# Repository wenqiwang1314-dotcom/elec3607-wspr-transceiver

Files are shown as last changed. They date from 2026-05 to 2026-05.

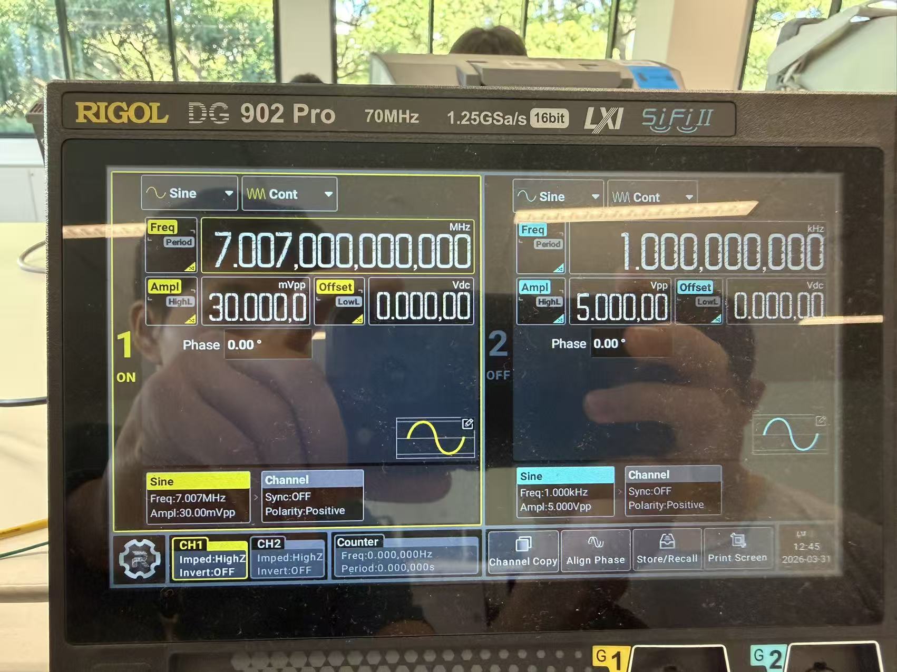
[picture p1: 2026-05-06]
report_images/partA_30mVpp_reference_input.jpg

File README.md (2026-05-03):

# ELEC3607 Assignment 1: WSPR Transceiver 任务设计

版本依据：Assignment 1 - WSPR Transceiver Version 0.4, 15 Apr 2026  
工程目录：`pcb_2026`  
原始 KiCad 工程：`bbb.kicad_pro`, `bbb.kicad_sch`, `bbb.kicad_pcb`  
最终提交：单个 `.zip`，包含 KiCad schematic、PCB design files、IEEE conference format 报告。

## 1. 项目目标

本项目在实验课 WSPR-SDR 接收机基础上完成两个修改：

1. Part A：用 Si5351 剩余的 `CLK2` 输出实现 WSPR 发射软件，并通过硬连线 RF loopback 让已有接收机或教师 decoder board 解码。
2. Part B：从现有 PCB 出发，重新设计成收发一体 transceiver PCB。发射机输出需达到 `0.1 W into 50 ohms`，收发共用接收机 bandpass filter，收发切换由 GPIO 控制，新增器件来自 Element14 Australia。

评分重点不是解释旧 WSPR-SDR，而是清楚说明新增发射功能、RF loopback、功率放大、收发切换和 PCB 修改如何工作。

## 2. 本地 Resources 使用清单

| 资料 | 用途 |
|---|---|
| `Resources/wspr_coding_process.pdf` | Part A WSPR message 编码、symbol 生成、tone mapping 的主要依据。 |
| `Resources/Si5351-B.pdf` | Si5351 `CLK2` 输出频率、驱动强度、寄存器/I2C 控制和硬件限制。 |
| `Resources/QS11-2010-Taylor.pdf` | WSPR 协议背景、4-FSK、tone spacing、解码约束和报告引用。 |
| `Resources/Tayloe_mixer_x3a.pdf` | 原接收机 quadrature sampling/Tayloe mixer 信号路径说明。 |
| `Resources/A Comparison of Affordable, Self-Assembled Software-Defined Radio Receivers Using Quadrature Sampling Down-Conversion.pdf` | 报告风格和 SDR 接收架构描述参考。 |
| `Resources/ABCs of Probes 60W-6053-15.pdf` | 示波器探头、RF/低电平测量误差说明。 |
| `Resources/emc_and_signal_integrity_ce_magazine_march-april_1999.pdf` | PCB layout、RF grounding、return path 和串扰风险说明。 |
| `Resources/website.txt` | WSPR/SDR 相关网页入口。 |

## 3. 团队分工建议

| 角色 | 主要负责 | 输出物 |
|---|---|---|
| Software lead | `wspr_transmit` C 程序、WSPR 编码、Si5351 `CLK2` 控制、CLI 参数验证 | C 源码、运行说明、软件测试记录 |
| Hardware modification lead | Part A 现有 PCB 飞线/RF loopback/衰减网络/照片/测量 | 修改原理图、PCB 照片、测试数据 |
| RF/PCB lead | Part B PA、T/R switch、共享 BPF、KiCad schematic/PCB layout | 更新后的 `.kicad_sch`, `.kicad_pcb`, BOM |
| Report/integration lead | IEEE 报告、图表、参考文献、提交 zip 检查 | 4 页以内 PDF 报告、最终 zip |

每个人都需要能在 oral discussion 中解释自己部分之外的完整信号路径。

## 4. Part A 任务：WSPR 发射与 RF Loopback

### A1. 明确 WSPR 发射需求

- 输入格式：`./wspr_transmit CALLSIGN LOCATOR POWER`
- 示例：`./wspr_transmit VK2AAX QF56 3`
- CLI 参数检查：
  - callsign：合法 WSPR callsign 格式，报告中说明支持范围。
  - locator：4 字符 Maidenhead grid，例如 `QF56`。
  - power：WSPR dBm power code，示例 `3` 代表作业要求输入格式，实际含义需在报告中解释。
- 输出信号：
  - WSPR uses 4-FSK.
  - 每个 symbol 选择 4 个 tone 之一。
  - tone spacing 约 `1.4648 Hz`。
  - 一帧 WSPR 标准消息共 `162` symbols，持续约 `110.6 s`。
- 软件必须使用 Si5351 `CLK2` 产生 RF tone，不使用空中发射。

完成标准：

- 程序能接受示例命令并生成确定的 WSPR symbol/tone 序列。
- 参数错误时给出 usage。
- 报告中给出 symbol generation 流程图或伪代码。

### A2. 编写 `wspr_transmit` C 程序

建议文件：

- `software/wspr_transmit.c`
- `software/wspr_encode.c`
- `software/wspr_encode.h`
- `software/si5351_control.c`
- `software/si5351_control.h`
- `software/Makefile`

软件模块任务：

1. `main()` 解析 `CALLSIGN LOCATOR POWER`。
2. WSPR message packing：将 callsign、locator、power 打包成 WSPR message bits。
3. FEC/interleaving/sync：按 `Resources/wspr_coding_process.pdf` 生成 162 个 symbols。
4. Tone scheduler：将 symbol 映射到 `f0 + symbol * 1.4648 Hz`。
5. Si5351 driver：通过 I2C 更新 `CLK2` 输出频率。
6. Timing：每个 symbol 周期约 `110.592 / 162 = 0.6827 s`，尽量减少切换抖动。
7. Logging：启动时打印 callsign、locator、power、base frequency、frame start time。

建议测试：

- Unit test：固定输入 `VK2AAX QF56 3` 时 symbol 序列可重复。
- Dry run：不控制 Si5351，只打印 tone frequency 和 symbol index。
- Hardware run：连接示波器/频率计确认 `CLK2` 有 4 个细小频偏。

完成标准：

- `make` 后生成 `wspr_transmit`。
- `./wspr_transmit VK2AAX QF56 3` 能运行完整帧。
- 报告附核心 C 代码片段，不必粘贴全部文件。

### A3. 音频 loopback 小步验证

用途：在 RF loopback 之前先验证编码和解码链路。

任务：

- 生成等效 audio baseband 4-FSK tone 序列。
- 将 audio 输出接入现有接收/解码链路。
- 用实验室 receiver/decoder 确认 callsign、locator、power 可解出。

完成标准：

- 记录一次成功 decode 的截图或串口/终端输出。
- 在报告中说明 audio loopback 只是中间验证，不是最终 RF 方案。

### A4. RF loopback 硬件修改

目标：将 Si5351 `CLK2` RF 输出硬连线接回 receiver RF input，不经过天线空中传播。

建议电路：

```text
Si5351 CLK2
    |
    |-- DC blocking capacitor
    |
  resistive attenuator / level-setting network
    |
    |-- optional test point
    |
receiver RF input before existing bandpass/mixer chain
```

关键设计点：

- 不应直接把过大的 `CLK2` 方波灌入 receiver input。
- 通过电容隔直和电阻衰减控制接收机输入电平。
- 尽量保持短接线、公共地可靠、避免 RF pickup。
- 报告需要包含：
  - 修改电路图。
  - 修改后 PCB 照片。
  - 衰减网络计算。
  - 实测 `CLK2` 输出幅度、receiver input 幅度、decode 结果。

完成标准：

- 教师 decoder board 或本组 WSPR receiver 能从 RF loopback 解码。
- 测量记录包含仪器型号/探头设置/测量点。

### A5. Part A 测量清单

| 测量项 | 测量点 | 期望记录 |
|---|---|---|
| `CLK2` RF 输出 | Si5351 `CLK2` 或飞线起点 | 频率、幅度、波形 |
| 衰减后 RF | receiver input | 幅度，确认不会过载 |
| Tone spacing | `CLK2` 或 receiver output | 约 `1.4648 Hz` 间隔，或解释仪器分辨率限制 |
| Decode 结果 | WSPR receiver/decoder | callsign、locator、power、SNR/time offset/frequency offset |
| 电源电流 | 板级输入 | RX/TX 状态对比 |

## 5. Part B 任务：Transceiver PCB 设计

### B1. 建立 KiCad 修改分支

任务：

- 复制原始工程，避免破坏 baseline。
- 建议新文件命名：
  - `wspr_transceiver.kicad_pro`
  - `wspr_transceiver.kicad_sch`
  - `wspr_transceiver.kicad_pcb`
- 保持 PCB 外形尺寸与原始 `bbb.kicad_pcb` 一致。
- 保留原接收机必要链路，只修改收发相关电路。

完成标准：

- KiCad ERC/DRC 主要错误已处理或在报告中解释。
- 原始板框尺寸未改变。

### B2. Part B RF 信号路径定义

建议完整信号路径：

```text
TX mode:
Si5351 CLK2
 -> output shaping / attenuator
 -> driver / PA
 -> low-pass or harmonic filtering if required
 -> GPIO-controlled T/R switch
 -> shared bandpass filter
 -> 50 ohm RF output / loopback/test connector

RX mode:
50 ohm RF input
 -> GPIO-controlled T/R switch
 -> shared bandpass filter
 -> existing receiver mixer / audio chain
```

报告必须说明：

- GPIO 为 RX 时，PA 输出不能反灌 receiver。
- GPIO 为 TX 时，receiver input 被隔离或保护。
- Bandpass filter 被 TX 和 RX 共用，符合题目要求。
- 50 ohm 系统如何匹配。

### B3. 0.1 W into 50 ohms 设计计算

设计目标：

- 输出功率：`Pout = 0.1 W = 20 dBm`
- 负载：`R = 50 ohms`
- 正弦波等效：
  - `Vrms = sqrt(P * R) = sqrt(0.1 * 50) = 2.236 V`
  - `Vpk = 3.162 V`
  - `Vpp = 6.324 V`
  - `Irms = Vrms / R = 44.7 mA`

任务：

- 选择 PA 架构：小信号 driver + RF transistor/MOSFET，或可买到的 RF gain block/PA 器件。
- 计算所需 gain：由 Si5351 `CLK2` 可用输出电平推算到 `20 dBm`。
- 设计输出匹配网络和 bias。
- 检查功耗和热耗散。
- 检查 harmonic suppression，必要时加入 LPF 或利用共享 BPF 后的选择性。

完成标准：

- 报告给出 PA 电路图、关键元件值、偏置点、预期 gain、预期输出功率。
- BOM 中新增器件来自 Element14 Australia，并记录订购编号、封装、库存检查日期。

### B4. GPIO 控制收发切换

可选方案：

1. RF switch IC：GPIO 直接/经电平转换控制，优点是隔离度和插损明确。
2. 二极管/模拟开关方案：成本低，但需要认真计算 RF 隔离、插损和偏置。
3. 小继电器：隔离好，但体积、电流、切换速度和 PCB 尺寸可能不利。

任务：

- 确定 GPIO 电压标准和可用 pin。
- 设计默认安全状态：上电默认 RX 或 TX disabled。
- 增加 PA enable，避免 RX 时 PA 自激或泄漏。
- 在原理图中清楚标注 `TX_EN` 或 `TR_CTRL`。

完成标准：

- 原理图中可从 GPIO 追踪到 RF switch/PA enable。
- 报告给出 TX/RX 两种状态的开关真值表。

示例真值表：

| GPIO `TR_CTRL` | 模式 | PA | RF path |
|---|---|---|---|
| `0` | RX | Off | RF input -> BPF -> receiver |
| `1` | TX | On | PA -> BPF -> RF output |

### B5. PCB layout 修改任务

任务：

- 保持原 PCB 大小和安装孔。
- PA 到 RF connector 的路径短、宽度接近 50 ohm 微带线要求。
- PA 输出和 receiver input 保持物理隔离。
- RF switch 靠近 BPF 或 RF connector，减少 stub。
- PA 电源就近放置 decoupling capacitors。
- 高电流/高频回流路径下方保持连续地。
- 增加测试点：
  - `TP_CLK2`
  - `TP_PA_IN`
  - `TP_PA_OUT`
  - `TP_TR_CTRL`
  - `TP_RX_IN`

完成标准：

- KiCad DRC 通过，或每个剩余 issue 都有理由。
- 关键 RF 网络可在 PCB 上清楚追踪。
- 生成 Gerber/Drill/BOM/position files 供提交或制造参考。

### B6. Element14 器件选择任务

需要记录每个新增器件：

- Manufacturer part number
- Element14 order code
- Package/footprint
- Datasheet URL
- 关键参数：频率范围、gain、P1dB/output power、supply voltage、insertion loss/isolation/current rating
- 查询日期

候选类别：

- RF amplifier / transistor / MOSFET
- RF switch 或 PIN diode
- Matching inductors/capacitors
- Attenuator resistors
- RF connector / test point
- Power decoupling capacitors

注意：库存和价格会变化，最终报告中要写明查询日期。

## 6. 报告结构建议（IEEE Conference Format，最多 4 页）

建议页数分配：

| 部分 | 建议长度 | 内容 |
|---|---:|---|
| Title/Abstract | 0.25 页 | 一句话说明实现了 RF loopback transmitter 和 transceiver PCB redesign。 |
| I. Introduction | 0.25 页 | 项目目标、频段、WSPR-SDR 到 transceiver 的变化。 |
| II. Part A Transmitter Implementation | 1.25 页 | WSPR 编码、`CLK2` 发射、CLI、RF loopback、衰减计算、软件/硬件框图。 |
| III. Part A Measurements | 0.5 页 | 波形、频率、电平、decode 结果、照片。 |
| IV. Part B Transceiver Hardware | 1.25 页 | PA、0.1 W 计算、T/R switch、共享 BPF、GPIO 真值表、完整信号路径。 |
| V. PCB Layout and Expected Performance | 0.5 页 | PCB 截图、RF layout 决策、预期功率/隔离/风险。 |
| References | 0.25 页 | WSPR、Si5351、器件 datasheet、Resources 中论文。 |

报告中必须放在正文的证据：

- Part A 修改电路图。
- Part A 修改后 PCB 照片。
- `wspr_transmit` 核心 C 代码。
- Part A 测量数据和 decode 结果。
- Part B 完整 schematic。
- Part B PA 和 50 ohm 功率计算。
- Part B PCB layout 截图。
- 新增器件 BOM。

## 7. 最终提交检查表

- [ ] `wspr_transmit` C 源码和 Makefile 已包含在 zip 中。
- [ ] `./wspr_transmit VK2AAX QF56 3` 已测试。
- [ ] RF loopback 修改电路图已画出。
- [ ] 修改后 PCB 照片已放入报告。
- [ ] 至少一次 WSPR decode 成功结果已记录。
- [ ] Part B KiCad schematic 已更新。
- [ ] Part B PCB layout 已更新且板框尺寸不变。
- [ ] PA 设计目标达到 `0.1 W into 50 ohms`，计算写入报告。
- [ ] T/R switch 由 GPIO 控制，真值表写入报告。
- [ ] 新增器件均来自 Element14 Australia，BOM 包含 order code。
- [ ] ERC/DRC 已运行，剩余问题已解释。
- [ ] IEEE conference format 报告不超过 4 页。
- [ ] zip 中包含 report PDF、KiCad files、source code、必要图片/测量数据。

## 8. 风险与应对

| 风险 | 影响 | 应对 |
|---|---|---|
| WSPR 编码实现错误 | decoder 无法解码 | 先做 dry-run 和 audio loopback，再做 RF loopback。 |
| Si5351 频率更新时间抖动 | tone 不稳定，SNR 下降 | 预先计算 tone frequencies，symbol 边界只做必要 I2C 更新。 |
| RF loopback 电平过高 | receiver overload 或损坏 | 加电容隔直和可计算衰减网络，先从大衰减开始测试。 |
| PA harmonic 太高 | 输出不干净，decoder 测试失败 | 使用共享 BPF，必要时在 PA 后加 LPF。 |
| T/R switch 隔离不足 | TX 泄漏进 RX 或 RX 灵敏度下降 | 选择隔离度足够的 RF switch，layout 缩短 stub。 |
| PCB 尺寸限制 | 新增 PA/switch 放不下 | 优先使用小封装器件，并移除不必要测试结构。 |
| Element14 缺货 | BOM 不可采购 | 尽早锁定 2 个可替代器件并记录查询日期。 |

## 9. 建议时间线

| 时间 | 软件 | 硬件/PCB | 报告 |
|---|---|---|---|
| Day 1 | 完成 WSPR 编码资料阅读和代码框架 | 找到 `CLK2`、receiver input、可用 GPIO | 建立报告模板 |
| Day 2 | 完成 symbol 生成和 dry-run | 设计 Part A 衰减/loopback 电路 | 画 Part A 框图 |
| Day 3 | 接入 Si5351 `CLK2` 控制 | 焊接 Part A 修改并拍照 | 写 Part A 方法 |
| Day 4 | audio/RF loopback debug | 完成 Part B PA 和 T/R switch 原理图 | 加入测量表 |
| Day 5 | 整理代码和运行说明 | 完成 PCB layout 和 ERC/DRC | 写 Part B 设计 |
| Day 6 | 最终复测 | 生成 Gerber/BOM/截图 | 压缩到 4 页并交叉检查 |

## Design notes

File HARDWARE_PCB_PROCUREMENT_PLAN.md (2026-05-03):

# WSPR Transceiver 硬件 / PCB / 采购优先规划

起始日期：2026-04-28  
目标：优先解决采购周期长、PCB 返工慢、硬件风险高的问题。软件可以并行推进，但不能阻塞器件采购和 PCB 方案冻结。

## 1. 核心结论

硬件任务的关键路径是：

```text
确定 TX/RX RF 架构
 -> 选 PA 与 T/R switch
 -> Element14 下单主器件和备选器件
 -> 原理图冻结
 -> footprint/封装核对
 -> PCB layout 冻结
 -> ERC/DRC + Gerber/BOM 输出
 -> 板级 bring-up 测试
```

必须先采购的不是所有小阻容，而是这些长周期/易缺货/封装影响 PCB 的器件：

1. PA final transistor 或 RF gain block。
2. T/R switch：RF switch IC 或 PIN diode switch 所需二极管。
3. RF matching/filter 电感电容，尤其是 RF-grade C0G/NP0 和高 Q 电感。
4. SMA/RF connector、test point、attenuator/matching 电阻。
5. PA 电源去耦、电源开关/enable 相关器件。

## 2. 当前原板可复用信息

从现有工程可见的关键网络：

| 原板网名 | 用途 | 新设计动作 |
|---|---|---|
| `CLK2` | Si5351 剩余输出，用作 TX RF source | 接入 TX driver / PA input。 |
| `BPFIN` | bandpass filter input | 改成 T/R switch 后的共享 BPF 输入。 |
| `BPFOUT` | bandpass filter output | RX 时接 mixer，TX 时视滤波器方向和拓扑决定是否反向使用。 |
| `RFIN` | receiver RF input path | RX path 保留，TX 时隔离/保护。 |
| `RFOUT` | RF amplifier/mixer 相关输出网 | 核对原接收机链路，不要误接为 TX power output。 |
| `U2 Si5351A-B-GT` | 频率源 | `CLK2` 需要新增 TX path footprint 和 test point。 |
| `U6 SMA` | 原 RF 接口 | 尽量复用为收发共用 50 ohm RF port。 |

硬件规划应先在 KiCad 中把这些网名重命名/标注清楚，例如新增：

- `TX_RF_RAW`
- `TX_PA_IN`
- `TX_PA_OUT`
- `TR_CTRL`
- `PA_EN`
- `ANT_50R`
- `BPF_SHARED_IN`
- `BPF_SHARED_OUT`

## 3. 架构冻结：两套方案并行保底

### 方案 A：分立 PA + PIN diode T/R switch（推荐优先推进）

理由：

- 低频 HF/WSPR 更容易用分立器件实现 0.1 W。
- PIN diode 可覆盖作业可能的 HF 频率，器件便宜，封装好焊。
- 即使 switch 性能一般，也容易调试和解释。

信号路径：

```text
TX:
Si5351 CLK2
 -> attenuator / square-wave shaping
 -> driver transistor
 -> class-C / class-E-ish PA final
 -> low-pass / harmonic cleanup if needed
 -> PIN diode T/R switch
 -> shared BPF
 -> SMA 50 ohm

RX:
SMA 50 ohm
 -> PIN diode T/R switch
 -> shared BPF
 -> existing RX amplifier/mixer path
```

必须设计：

- PA 输出目标：`0.1 W = 20 dBm into 50 ohms`。
- `Vrms = sqrt(0.1 * 50) = 2.236 V`
- `Vpp = 2 * sqrt(2) * 2.236 = 6.32 Vpp`
- `Irms = 2.236 / 50 = 44.7 mA`
- PA 要留 3 dB 余量，设计目标建议为 `23 dBm`，实际通过衰减或偏置调到 20 dBm。

采购优先件：

- 2N7000 / BS170 类 MOSFET 先买一批用于原型验证。
- RF BJT 小信号 driver 先买 5-10 个。
- PIN diode 至少买两种：低电阻优先、封装易焊优先。
- RF 电感电容按计算值上下各买一档。

### 方案 B：RF gain block + switch IC（作为备选）

理由：

- 原理图更整洁，50 ohm 接口明确。
- 缺点是价格高、频率下限/输出功率可能不完全满足。

注意：

- 搜到的 HMC741ST89ETR 是 50 MHz 到 3 GHz、输出约 +18.5 dBm 级别，单颗离 20 dBm 目标略低，而且若项目频率在 HF，需要确认 50 MHz 下限是否不可接受。
- 很多现成 RF switch IC 下限从 100 MHz、1 GHz 或更高开始，不适合 HF WSPR，不能只看“SPDT RF switch”就下单。
- 如果选 switch IC，必须确认 minimum frequency、power handling、insertion loss、isolation、control voltage 和 footprint。

## 4. Element14 初筛器件方向

下表是采购前筛选方向，不是最终 BOM。下单前必须重新打开 Element14 页面确认库存、交期、价格和是否停产。

| 类别 | 候选方向 | 初筛观察 | 风险 |
|---|---|---|---|
| PA final | 2N7000 / BS170 类小 MOSFET | Element14 上 2N7000 有大量库存记录，便宜且易原型 | 不是专用 RF PA，HF 输出功率和效率要实测。 |
| RF driver | BFR92/BFR106 类 RF BJT | Element14 有 RF transistor 分类，SOT-23 易布局 | 需要偏置设计，不能直接当 100 mW final。 |
| PIN diode | BAR50 / BAP65 / HSMP 类 | PIN diode 适合 RF switch/attenuator，部分型号覆盖 10 MHz 以上 | 某些型号可能 no longer manufactured，要买替代件。 |
| RF switch IC | BGSA11 / F2912 / ADRF 系列 | 部分器件为 50 ohm switch，控制简单 | 频率下限、价格、封装和焊接难度可能不适合本作业。 |
| RF gain block | HMC741ST89E 类 | 50 ohm gain block、SOT-89、资料完整 | 频率下限 50 MHz，输出功率略低于 20 dBm 目标。 |
| L/C matching | C0G/NP0 RF capacitors，高 Q inductors | 影响 PA matching 和滤波器性能 | 普通 X7R 不适合频率/稳定性关键位置。 |

参考链接：

- Element14 2N7000: https://au.element14.com/on-semiconductor/2n7000/mosfet-n-channel-200ma-60v-to/dp/9845178
- Element14 BAR50-02V: https://au.element14.com/infineon/bar50-02v/diode-rf-pin-sc-79/dp/1095645
- Element14 HMC741ST89ETR: https://au.element14.com/analog-devices/hmc741st89etr/rf-amplifier-50mhz-to-3ghz-sot/dp/4419988
- Element14 RF / PIN diode category: https://au.element14.com/c/semiconductors-discretes/diodes-rectifiers/rf-pin-diodes

## 5. 采购策略：今天就能下的单

### 第一单：风险样品单（今天或最晚明天）

目的：不等最终 PCB，先买会影响架构的器件。

建议数量：

| 器件类别 | 数量 | 原因 |
|---|---:|---|
| PA final MOSFET/BJT 候选 | 每种 5-10 | 焊坏、调偏置、做 dead-bug 原型都需要余量。 |
| RF driver transistor | 5-10 | 驱动级可换型。 |
| PIN diode 候选 | 每种 10-20 | switch 可能要用 2-4 颗，且要做多种拓扑。 |
| RF C0G 电容 | 每值 10-20 | matching/filter 调试要换值。 |
| RF 电感 | 每值 5-10 | PA 输出网络和 LPF 调试。 |
| 50 ohm/attenuator 电阻 | 每值 20 | Pi/T attenuator 与终端匹配。 |
| SMA/test point | 2-5 | PCB 与飞线测试都需要。 |

第一单原则：

- 买主方案和备选方案，不要只买一个“看起来最对”的器件。
- 对 switch IC 这类贵/难焊器件，除非频率下限和封装已经确认，否则先不要压预算。
- 所有新增封装优先选 KiCad 标准库已有 footprint：SOT-23、SOT-223、SOT-89、0805、0603、SMA edge/through-hole。

### 第二单：PCB BOM 冻结单

触发条件：

- PA topology 已在面包板/dead-bug 或小板上能接近 20 dBm。
- T/R switch 在 RX/TX 两态下能连通/隔离。
- KiCad footprint 与 datasheet land pattern 已核对。

第二单内容：

- 最终型号主件。
- 最终 matching/filter 值。
- 备用器件 20%-50%。
- PCB assembly 需要的 reel/cut-tape 封装选项。

## 6. 日期规划（从 2026-04-28 开始）

| 日期 | 硬件/采购目标 | 输出物 | 是否阻塞 PCB |
|---|---|---|---|
| Apr 28 | 冻结 TX/RX 总体架构，列出 PA 与 switch 两套候选 | `hardware_decision_log.md` 初版，采购 basket 初版 | 是 |
| Apr 29 | 完成 Element14 第一单，下单主件+备选+RF L/C | 订单截图/BOM 记录，datasheet 链接 | 是 |
| Apr 30 | 画 Part B 原理图草案：PA、T/R switch、shared BPF 接法 | KiCad schematic draft | 是 |
| May 1 | footprint 核对，确定板上可放位置，检查原板尺寸 | footprint checklist，placement sketch | 是 |
| May 2 | PCB layout 第 1 版：只追关键 RF path 和电源路径 | `wspr_transceiver.kicad_pcb` v1 | 否 |
| May 3 | ERC/DRC 第 1 轮，生成 BOM 草案 | DRC log，BOM v1 | 否 |
| May 4 | 器件到货后做 PA/switch 台架验证；若未到货，用仿真/计算补齐 | PA/switch measurement plan | 否 |
| May 5 | 根据实测或 datasheet 修正匹配、偏置、滤波器 | schematic v2，BOM v2 | 是 |
| May 6 | PCB layout 冻结，导出 Gerber/Drill/position | fabrication package | 是 |
| May 7+ | Bring-up/报告证据收集 | 波形、功率、切换真值表、照片 | 否 |

如果最终提交日期早于这个节奏，需要把 May 4 以后的“实测”改成“prototype test + expected performance”，但采购和 PCB 冻结仍然要在前两天完成。

## 7. 每日硬件检查表

### Day 0 / Apr 28

- [ ] 在 KiCad 中确认 `CLK2` 到新增 TX path 的可布线路径。
- [ ] 确认 SMA 到 BPF 的原始路径，决定 BPF 是否可双向共享。
- [ ] 决定 `TR_CTRL` GPIO 使用哪个 BeagleBone/board header pin。
- [ ] 建立候选 BOM 表，至少每个关键类别 2 个候选。
- [ ] 采购负责人把 Element14 basket 分享给全组复核。

### Day 1 / Apr 29

- [ ] 下第一单。
- [ ] 下载每个新增器件 datasheet，放到 `Resources/datasheets/`。
- [ ] 在 BOM 表记录 order code、数量、价格、库存、预计到货日期、查询日期。
- [ ] KiCad 新增 symbol/footprint 前先确认封装尺寸。

### Day 2 / Apr 30

- [ ] 画 PA 偏置、电源去耦、input attenuator。
- [ ] 画 T/R switch，包含 TX/RX 真值表。
- [ ] 明确 RX 保护：TX 时 receiver input 不可直接承受 PA 输出。
- [ ] 明确 TX harmonic cleanup：BPF 是否足够，不足则加 LPF。

### Day 3 / May 1

- [ ] 把关键器件放入 PCB：PA 靠近 BPF/switch，Si5351 `CLK2` 到 PA input 短。
- [ ] PA 电源走线加粗，就近放 `100 nF + 1 uF/10 uF`。
- [ ] 新增 test points：`TP_CLK2_TX`, `TP_PA_IN`, `TP_PA_OUT`, `TP_TR_CTRL`, `TP_ANT_50R`。
- [ ] 检查地回流：PA、switch、BPF 下方尽量连续地。

### Day 4 / May 2

- [ ] 完成 RF path layout。
- [ ] 检查 board outline 与原 `bbb.kicad_pcb` 一致。
- [ ] 关键 RF 线尽量短、少过孔、少 stub。
- [ ] 输出 Gerber 预览截图给报告使用。

## 8. PCB 设计冻结标准

### 原理图冻结必须满足

- [ ] `CLK2 -> PA -> T/R switch -> shared BPF -> SMA` TX path 可追踪。
- [ ] `SMA -> T/R switch -> shared BPF -> RX` RX path 可追踪。
- [ ] `TR_CTRL` GPIO 控制 switch。
- [ ] `PA_EN` 或同等机制保证 RX 时 PA 关闭。
- [ ] 所有 RF port 有 DC blocking 或明确 DC bias 处理。
- [ ] PA 输出功率计算写在原理图 note 或报告草稿中。

### PCB 冻结必须满足

- [ ] 板框尺寸不变。
- [ ] 新增器件 footprint 与 datasheet land pattern 对照完成。
- [ ] PA 输出到 BPF/switch/SMA 的路径最短。
- [ ] RX input 和 PA output 不平行长距离靠近。
- [ ] 每个新增 IC/PA 管有近端 decoupling。
- [ ] DRC 通过，或剩余 DRC issue 有说明。
- [ ] 生成 Gerber/Drill/BOM/position files。

## 9. Bring-up 测试顺序

不能第一次上电就直接发 0.1 W。顺序如下：

1. 不焊 PA final，检查 3.3 V/5 V 电源和 `TR_CTRL`。
2. 焊 switch，低功率信号源测 RX path 插损和 TX path 连通。
3. 焊 PA driver，不焊 final 或限流供电，测 `CLK2` 到 `PA_IN`。
4. 焊 PA final，先接 20 dB attenuator + 50 ohm dummy load。
5. 从低 duty / 短时间 TX 开始，测电流和输出波形。
6. 达到接近 20 dBm 后再接共享 BPF，检查谐波/输出电平。
7. 切 RX 模式，确认 PA 关闭且 receiver 没有被强信号损坏。

报告证据：

- TX output into 50 ohm 的电压或功率计算。
- `TR_CTRL=0/1` 的状态表。
- PA 输出和 BPF 后输出波形。
- PCB layout 截图。
- 新增 BOM 表和 Element14 order code。

## 10. 风险优先级

| 优先级 | 风险 | 立即动作 |
|---|---|---|
| P0 | 买不到合适 T/R switch | 同时采购 PIN diode 和至少一个 switch IC 备选；方案 A 不依赖高价 IC。 |
| P0 | PA 达不到 20 dBm | PA 设计留 3 dB 余量；买 driver/final 多种候选；预留可调 matching。 |
| P1 | BPF 双向共享后插损/匹配变差 | PCB 上预留 0 ohm / DNP 位置，可改接 BPF 方向或旁路测试。 |
| P1 | TX 泄漏损坏 RX | RX path 加隔离和保护，bring-up 使用 attenuator/dummy load。 |
| P1 | 封装太难焊 | 优先选 SOT-23/SOT-89/0805，LGA/QFN 只作备选。 |
| P2 | PCB 空间不够 | 先放 PA/switch/BPF/SMA，其他测试点可删减。 |

## 11. 给团队的执行规则

- 硬件负责人每天更新一次 BOM 和 decision log。
- 采购下单不等软件完成。
- 每个关键器件至少有一个备选。
- 下单前必须由另一名组员复核 datasheet 的 frequency、power、voltage、footprint。
- 任何“看起来可以”的 RF switch，必须先查 minimum operating frequency。
- 报告里只写最终采用方案，但保留 decision log 供 oral discussion 解释为什么没选其他方案。

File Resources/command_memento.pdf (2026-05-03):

## GNU/Linux most wanted

## Summary of most useful commands

©Copyright 2025-2005, Bootlin.
Free to share under the terms of the Creative Commons Attribution-ShareAlike 3.0 license (http://creativecommons.org)

Electronic version, sources, translations and updates: http://bootlin.com/doc/legacy/command-line/ (http://free-electrons.com/doc/legacy/command-line/)

Thanks to Michel Blanc, Hermann J. Beckers and Thierry Grellier.

Latest update: Oct 28, 2025

## Handling files and directories

Create a directory:

## mkdir dir

Create nested directories:

## mkdir -p dir1/dir2

Changing directories:

## cd newdir

cd .. (parent directory)
cd - (previous directory)
cd (home directory)
cd ~bill (home directory of user bill)

Print the working (current) directory: pwd
Copy a file to another:

## cp source_file dest_file

Copy files to a directory:

## cp file1 file2 dir

Copy directories recursively:

## cp -r source_dir dest_dir rsync -a source_dir/ dest_dir/

Create a symbolic link:

## ln -s linked_file link

Rename a file, link or directory:

## mv source_file dest_file

Remove files or links:

## rm file1 file2

Remove empty directories:

## rmdir dir

Remove non-empty directories:

## rm -rf dir Listing files

List all “regular” files (not starting with .) in the current directory:
ls

Display a long listing:

## ls -l

List all the files in the current directory, including “hidden” ones (starting with .):

## ls -a

List by time (most recent files first):

## ls -t

List by size (biggest files first)

## ls -S

List with a reverse sort order:

## ls -r

Long list with most recent files last:

## ls -ltr Displaying file contents

Concatenate and display file contents:

## cat file1 file2

Display the contents of several files (stopping at each page):

## more file1 file2

less file1 file2 (better: extra features)

Display the first 10 lines of a file:

## head -10 file

Display the last 10 lines of a file:

## tail -10 file File name pattern matching

Concatenate all “regular” files:

## cat *

Concatenate all “hidden” files:

## cat .*

Concatenate all files ending with .log:

## cat *.log

List “regular” files with bug in their name:

## ls *bug*

List all “regular” files ending with . and a single character:
ls *.?

## Handling file contents

Show only the lines in a file containing a given substring:

## grep substring file

Case insensitive search:

## grep -i substring file

Showing all the lines but the ones containing a substring:

## grep -v substring file

Search through all the files in a directory:

## grep -r substring dir

Sort lines in a given file:

## sort file

Sort lines, only display duplicate ones once:

## sort -u file (unique) Changing file access rights

Add write permissions to the current user:

## chmod u+w file

Add read permissions to users in the file group:

## chmod g+r file

Add execute permissions to other users:

## chmod o+x file

Add read + write permissions to all users:

## chmod a+rw file

Make executable files executable by all:

## chmod a+rX *

Make the whole directory and its contents accessible by all users:

## chmod -R a+rX dir (recursive)

## Comparing files and directories

Comparing 2 files:

## diff file1 file2

Comparing 2 files (graphical):

## gvimdiff file1 file2 tkdiff file1 file2 meld file1 file2

Comparing 2 directories:

## diff -r dir1 dir2 Looking for files

Find all files in the current (.) directory and its subdirectories with log in their name:

## find . -name “*log*”

Find all the .pdf files in dir and subdirectories and run a command on each:

## find . -name “*.pdf” -exec xpdf {} ';'

Quick system-wide file search by pattern (caution: index based, misses new files):

## locate “*pub*” Redirecting command output

Redirect command output to a file:

## ls *.png > image_files

Append command output to an existing file:

## ls *.jpg >> image_files

Redirect command output to the input of another command:

## cat *.log | grep error Job control

Show all running processes:

## ps -ef

Live hit-parade of processes (press P, M, T: sort by Processor, Memory or Time usage):

## top

Send a termination signal to a process:
kill <pid> (number found in ps output)

Have the kernel kill a process:

## kill -9 <pid>

Kill all processes (at least all user ones):

## kill -9 -1

Kill a graphical application:
xkill (click on the program window to kill)

## File and partition sizes

Show the total size on disk of files or directories (disk usage):

## du -sh dir1 dir2 file1 file2

Number of bytes, words and lines in file:
wc file (word count)

Show the size, total space and free space of the current partition:
df -h .

Display these info for all partitions:

## df -h Compressing

Compress a file:

## gzip file (.gz format)

bzip2 file (.bz2 format, better)
lzma file (.lzma format, best compression) xz file (.xz format, best for code)

Uncompress a file:

## gunzip file.gz bunzip2 file.bz2 unlzma file.lzma unxz file.xz Archiving

Create a compressed archive (tape archive):

## tar zcvf archive.tar.gz dir tar jcvf archive.tar.bz2 dir tar Jcvf archive.tar.xz dir tar --lzma -cvf archive.tar.lzma

Test (list) a compressed archive:

## tar tvf archive.tar.[gz|bz2|lzma|xz]

Extract the contents of a compressed archive:

## tar xvf archive.tar.[gz|bz2|lzma|xz]

tar options:
c: create
t: test
x: extract
j: on the fly bzip2 (un)compression J: on the fly xz (un)compression
z: on the fly gzip (un)compression

Handling zip archives

## zip -r archive.zip <files> (create) unzip -t archive.zip (test / list) unzip archive.zip (extract) Printing

Send PostScript or text files to queue:

## lpr -Pqueue f1.ps f2.txt (local printer)

List all the print jobs in queue:

## lpq -Pqueue

Cancel a print job number in queue:

## cancel 123 queue

Print a PDF file:

## pdf2ps doc.pdf lpr doc.ps

View a PostScript file:

## ps2pdf doc.ps xpdf doc.pdf User management

List users logged on the system:

## who

Show which user I am logged as:

## whoami

Show which groups user belongs to:

## groups user

Tell more information about user:

## finger user

Switch to user hulk:

## su - hulk

Switch to super user (root):
su - (switch user)
su (keep same directory and environment)

## Time management

Wait for 60 seconds:

## sleep 60

Show the current date:

## date

Count the time taken by a command:

## time find_charming_prince -cute -rich Command help

Basic help (works for most commands):

## grep --help

Access the full manual page of a command:

## man grep Misc commands

Basic command-line calculator

## bc -l Basic system administration

Change the owner and group of a directory and all its contents:

## sudo chown -R newuser.newgroup dir

Reboot the machine in 5 minutes:

## sudo shutdown -r +5

Shutdown the machine now:

## sudo shutdown -h now

Display all available network interfaces:

## ip -a

Assign an IP address to a network interface:

## sudo ip addr add 207.46.130.108/24 dev eth0

Bring up/down a network interface:

## sudo ip link set eth0 [up|down]

Define a default gateway for packets to machines outside the local network: sudo ip route add default via 192.168.0.1
Delete the default route:
sudo ip route del default via 192.168.0.1
Test networking with another machine:

## ping 207.46.130.108

Create or remove partitions on the first IDE hard disk:

## fdisk /dev/hda1

Create (format) an ext3 filesystem:

## mkfs.ext3 /dev/hda1

Create (format) a FAT32 filesystem:

## mkfs.vfat -v -F 32 /dev/hda2

Mount a formatted partition:

## mkdir /mnt/usbdisk (just do it once) sudo mount /dev/uba1 /mnt/usbdisk

Mount a filesystem image (loop device):

## sudo mount -o loop fs.img /mnt/fs

Unmount a filesystem:

## sudo umount /mnt/usbdisk

Check the system kernel version:

## uname -a

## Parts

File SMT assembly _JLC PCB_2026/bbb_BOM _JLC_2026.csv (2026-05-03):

Comment | Designator | Footprint
0.1uF | C1,C3,C4,C5,C6,C7,C8,C9,C10 | Capacitor_SMD:C_0805_2012Metric
0.01uF | C2 | Capacitor_SMD:C_0805_2012Metric
3300pF | C11,C12 | Capacitor_SMD:C_0805_2012Metric
100nF | C13 | Capacitor_SMD:C_0805_2012Metric
10uF | C14 | Capacitor_SMD:C_0805_2012Metric
33pF | C20,C25,C29 | Capacitor_SMD:C_0805_2012Metric
27pF | C21,C26,C30 | Capacitor_SMD:C_0805_2012Metric
270pF | C22 | Capacitor_SMD:C_0805_2012Metric
680pF | C23,C27,C31 | Capacitor_SMD:C_0805_2012Metric
22pF | C24,C28,C32 | Capacitor_SMD:C_0805_2012Metric
TestPoint_Small | CLK0_TP4,CLK1_TP5,Iout_TP6,Qout_TP7,RFIN_TP7,RFOUT_TP8,SCL_TP2,SDA_TP3,XA_TP1 | TestPoint:TestPoint_Keystone_5000-5004_Miniature
LED yellow | D1 | Diode_SMD:D_0603_1608Metric
LED blue | D2 | Diode_SMD:D_0603_1608Metric
GND BRIDGE | GND_TP0 | TestPoint:TestPoint_Bridge_Pitch7.62mm_Drill1.3mm
Conn_02x14_Odd_Even | J1 | Connector_PinHeader_2.54mm:PinHeader_2x14_P2.54mm_Vertical
Conn_02x20_Odd_Even | J2 | Connector_PinHeader_2.54mm:PinHeader_2x20_P2.54mm_Vertical
FC68131 | J3 | AudioJack:FC68131
Inductor L1 | J4 | TerminalBlock_Phoenix:TerminalBlock_Phoenix_MPT-0,5-2-2.54_1x02_P2.54mm_Horizontal
Inductor L2 | J5 | TerminalBlock_Phoenix:TerminalBlock_Phoenix_MPT-0,5-2-2.54_1x02_P2.54mm_Horizontal
Inductor L3 | J6 | TerminalBlock_Phoenix:TerminalBlock_Phoenix_MPT-0,5-2-2.54_1x02_P2.54mm_Horizontal
470 | R1,R3 | Resistor_SMD:R_0805_2012Metric
47 | R2 | Resistor_SMD:R_0805_2012Metric
220 | R4 | Resistor_SMD:R_0805_2012Metric
4.7k | R5,R6 | Resistor_SMD:R_0805_2012Metric
100 | R7 | Resistor_SMD:R_0805_2012Metric
10K | R8,R9 | Resistor_SMD:R_0805_2012Metric
62 | R10 | Resistor_SMD:R_0805_2012Metric
200 | R11 | Resistor_SMD:R_0805_2012Metric
50 | R20,R21 | Resistor_SMD:R_0805_2012Metric
THS4304 | U1 | Package_TO_SOT_SMD:SOT-23-5
Si5351A-B-GT | U2 | Package_SO:MSOP-10_3x3mm_P0.5mm
TS3A5017 | U3 | Package_SO:SOIC-16_3.9x9.9mm_P1.27mm
TL972 | U4 | Package_SO:SOIC-8-1EP_3.9x4.9mm_P1.27mm_EP2.29x3mm
LD1117S33TR_SOT223 | U5 | Package_TO_SOT_SMD:SOT-223-3_TabPin2
BWSMA-KE-P001 | U6 | BWSMA-KE-P001:BWSMA-KE-P001
Crystal | Y1 | Crystal:Crystal_SMD_TXC_7M-4Pin_3.2x2.5mm

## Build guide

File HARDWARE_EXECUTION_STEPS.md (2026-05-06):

# WSPR Transceiver 硬件负责人执行步骤

负责人范围：Part A 的 RF loopback 硬件改造 + Part B 的 transceiver PCB 新硬件设计。  
起始日期：2026-05-03。  
目标：尽快冻结硬件方案、采购关键器件、完成 KiCad 原理图和 PCB，并为报告准备可解释的设计证据。

## 0. 你要交付什么

你的硬件部分最终必须能回答这几个问题：

1. `CLK2` 发射信号如何进入 RF 发射链路？
2. 发射输出如何达到 `0.1 W into 50 ohms`？
3. 发射器和接收器如何共用原来的 bandpass filter？
4. GPIO 如何切换 TX/RX？
5. TX 时如何保护 RX 输入，RX 时如何关闭/隔离 PA？
6. PCB 尺寸如何保持与原板一致？
7. 新增器件为什么这样选，是否来自 Element14 Australia？

## 1. 第一天：先锁定原板 RF 路径

打开 KiCad 工程：

- `bbb.kicad_pro`
- `bbb.kicad_sch`
- `bbb.kicad_pcb`

在 schematic 和 PCB 中标记这些网络：

| 网名 | 你要确认的内容 |
|---|---|
| `CLK2` | Si5351 剩余输出，作为 TX RF source。 |
| `BPFIN` | 原 bandpass filter 输入。 |
| `BPFOUT` | 原 bandpass filter 输出。 |
| `RFIN` | 原 receiver RF input path。 |
| `RFOUT` | 原 RF amplifier/mixer 相关网络，注意不要误认为最终 TX output。 |
| `U6 SMA` | 原 RF 接口，优先复用为收发共用 50 ohm 端口。 |

执行动作：

1. 在原理图截图上用箭头画出原 RX 路径：

```text
SMA / RFIN -> BPFIN -> BPF -> BPFOUT -> receiver amplifier/mixer
```

2. 在 PCB 截图上圈出：
   - Si5351 `U2`
   - `CLK2`
   - BPF 电容/电感区域
   - SMA `U6`
   - receiver input/mixer 区域

3. 保存两张截图给报告使用：
   - `report_images/original_rf_path_schematic.png`
   - `report_images/original_rf_path_pcb.png`

完成标准：

- 你能指着图解释 RX 信号从 SMA 到 mixer 的路径。
- 你能说出 TX 新电路要插入在哪里。

## 1A. 根据 `BBBSchematic.jpg` 精确确定硬件架构

这张图不是只用来看元件名，而是用来决定 transceiver 的切入点。先按下面顺序把原板分成 6 个功能块。

### 1A.1 原接收机 RF 路径

从 `BBBSchematic.jpg` 可以读出原接收链：

```text
U6 SMA connector
 -> BPFIN
 -> Band Pass Filter
    R20, C20-C32, J4/J5/J6 external inductors, R21
 -> BPFOUT / RFIN
 -> C2 AC coupling
 -> U1 THS4304 RF amplifier
 -> RFOUT
 -> U3 TS3A5017 Tayloe / quadrature mixer
 -> MIXI+, MIXI-, MIXQ+, MIXQ-
 -> U4 TL972 audio amplifier
 -> J3 audio jack, Iout/Qout
```

这说明原板真正的 RF input/output 关系是：

| 位置 | 图中标号 | 硬件含义 |
|---|---|---|
| RF connector | `U6` | SMA 接口，当前只作为接收输入。 |
| BPF input | `BPFIN` | SMA 后进入 bandpass filter 的一端。 |
| BPF output | `BPFOUT` | bandpass filter 输出端。 |
| RX amplifier input | `RFIN` / `RFIN_TP7` | 与 `BPFOUT` 同一输入区域，经 `C2` 进入 U1。 |
| RX amplifier output | `RFOUT` / `RFOUT_TP8` | U1 输出，送入 mixer。 |
| Mixer input | `MIXIN` | U3 TS3A5017 的 RF mixer input。 |

结论：Part B 不应该把 PA 接到 `RFOUT`。`RFOUT` 是接收机 RF amplifier 的输出，不是天线输出。TX power path 应围绕 `CLK2`、`BPFOUT/BPFIN` 和 SMA 重新设计。

### 1A.2 原时钟和可用 TX 源

图中 `U2 Si5351A-B-GT` 有 3 个输出：

| Si5351 输出 | 原用途 | 新设计动作 |
|---|---|---|
| `CLK0` | 送 mixer 的 0 度 LO，标成 `MIXCLK0` | 保留，不改。 |
| `CLK1` | 送 mixer 的 90 度 LO，标成 `MIXCLK90` | 保留，不改。 |
| `CLK2` | 已引出但未用于 RX 主链 | 作为 WSPR TX RF source。 |

结论：TX 链从 `CLK2` 开始，不能占用 `CLK0/CLK1`，否则会破坏接收机 mixer。

### 1A.3 最推荐的 Part B 架构

为了最少改动原接收机，同时满足“发射机与接收机共用 bandpass filter”，推荐架构如下：

```text
RX mode:
SMA U6
 -> BPFIN
 -> shared BPF
 -> BPFOUT
 -> T/R switch RX throw
 -> RFIN / C2
 -> U1 THS4304
 -> RFOUT
 -> U3 mixer
 -> I/Q audio

TX mode:
Si5351 CLK2
 -> DC block / attenuator
 -> TX driver
 -> PA final
 -> PA output matching / optional LPF
 -> T/R switch TX throw
 -> BPFOUT
 -> shared BPF used in reverse direction
 -> BPFIN
 -> SMA U6
 -> 50 ohm load
```

这个方案的核心切入点是 `BPFOUT/RFIN`：

- `BPFOUT` 是 BPF 和 receiver amplifier 之间的天然分界点。
- 在 RX 模式，`BPFOUT` 接回 `RFIN/C2/U1`，原接收机照常工作。
- 在 TX 模式，`BPFOUT` 从 receiver input 断开，改接 PA output，让 TX 信号反向通过同一个 BPF 到 SMA。
- BPF 是 LC 被动网络，理论上双向可用；但原板的 50 ohm 电阻和实际插损必须测量/计算。

### 1A.4 为什么不从其他位置接入

不要选择这些错误切入点：

| 错误切入点 | 问题 |
|---|---|
| `RFOUT` | 这是 U1 接收放大器输出，会把 TX 功率打进 mixer 区域，不能作为天线输出。 |
| `MIXIN` | 这是 mixer input，不经过 BPF，也不能输出 0.1 W。 |
| `CLK0` / `CLK1` | 已用于 quadrature mixer LO，占用后 RX 不工作。 |
| SMA 直接并联 PA output | RX input 和 PA output 会互相加载，TX 时可能损坏 receiver。 |
| 另加独立 BPF | 不满足“发射器应与接收器共用 bandpass filter”的要求。 |

### 1A.5 必须复核的 R20 / R21

图中 BPF 两端有两个关键 50 ohm 电阻：

- `R20 = 50 ohm`，在 `BPFIN` 进入 BPF 的位置。
- `R21 = 50 ohm`，在 `BPFOUT` 端附近。

这两个元件在接收机里可能用于滤波器匹配/终端，但在 100 mW TX 路径里会影响功率。

你必须做以下判断：

1. 在 TX 模式，`R21` 是否会变成 PA output 的额外 50 ohm shunt load？
2. 在 TX 模式，`R20` 是否会成为 SMA 前的 50 ohm series loss？
3. 如果保留 R20/R21，PA 需要输出多少功率才能保证 SMA 外接 50 ohm load 上得到 0.1 W？
4. 如果 R21 会明显吃掉 TX 功率，是否应把 R21 改成：
   - DNP footprint；
   - 只在 RX 模式接入的 switchable termination；
   - 或移到 T/R switch 的 RX throw 后面。
5. 如果 R20 造成明显插损，是否应改成：
   - 0 ohm / small matching resistor；
   - RF-rated resistor；
   - 或重新计算 BPF matching。

报告中不要只写“使用原 BPF”。必须写清楚 R20/R21 对 TX 输出功率的影响，并说明最终是保留、改值、DNP，还是切换接入。

### 1A.6 精确的 T/R switch 定义

建议把 T/R switch 放在 `BPFOUT` 与 `RFIN/C2` 之间。

推荐网络命名：

```text
BPFOUT_SHARED      BPF 的 BPFOUT 端
RX_RFIN_SWITCHED   接回 C2/U1 的 RX input
TX_PA_FILTERED     PA output/matching 后的 TX 信号
TR_CTRL            GPIO 控制信号
PA_EN              PA 使能信号
```

逻辑关系：

| `TR_CTRL` | `PA_EN` | 模式 | Switch 状态 | RF path |
|---|---|---|---|---|
| 0 | 0 | RX | `BPFOUT_SHARED -> RX_RFIN_SWITCHED` | SMA -> BPFIN -> BPF -> U1/U3 |
| 1 | 1 | TX | `TX_PA_FILTERED -> BPFOUT_SHARED` | CLK2 -> PA -> BPF reverse -> SMA |

默认安全状态应为 RX：

- 上电时 `TR_CTRL = 0`。
- 上电时 `PA_EN = 0`。
- 软件只有在准备 TX 时才拉高 `TR_CTRL` 和 `PA_EN`。

### 1A.7 你在 KiCad 中要做的精确修改

在 `wspr_transceiver.kicad_sch` 中按这个顺序改：

1. 保留 `U6 -> BPFIN -> BPF -> BPFOUT`。
2. 断开 `BPFOUT/RFIN` 直接进入 `C2/U1` 的连接。
3. 在断开点加入 RF SPDT / PIN diode switch。
4. RX throw 连接到原 `RFIN -> C2 -> U1`。
5. TX throw 连接到 `TX_PA_FILTERED`。
6. `TX_PA_FILTERED` 来自：

```text
CLK2 -> DC block -> attenuator -> driver -> PA final -> matching/LPF
```

7. 增加 `PA_EN` 控制 PA 偏置或供电。
8. 增加 `TR_CTRL` 控制 T/R switch。
9. 在这些点加 test points：

```text
TP_CLK2_TX
TP_TX_PA_IN
TP_TX_PA_OUT
TP_TX_FILTERED
TP_BPFOUT_SHARED
TP_TR_CTRL
TP_PA_EN
TP_ANT_50R
```

### 1A.8 需要量出来或算出来的数据

根据 `BBBSchematic.jpg`，你需要为硬件报告准备这些数据：

| 数据 | 测量/计算位置 | 目的 |
|---|---|---|
| BPF passband loss | `BPFIN` 到 `BPFOUT` | 判断 TX 反向通过 BPF 后还剩多少功率。 |
| R20/R21 power dissipation | BPF 两端 50 ohm 元件 | 确认 0805 resistor 不过热且不吞掉太多功率。 |
| PA output before BPF | `TX_PA_OUT` 或 `TX_FILTERED` | 确认 PA 本身能达到目标。 |
| Final output power | SMA 外接 50 ohm load | 证明符合 `0.1 W into 50 ohms`。 |
| RX isolation during TX | `RFIN/C2` 处 | 确认 TX 不会打进 U1。 |
| RX path insertion loss | RX mode 下 SMA 到 `RFIN` | 确认新增 switch 没明显损坏接收性能。 |

最终验收时以 SMA 外接 50 ohm dummy load 上的功率为准：

```text
0.1 W into 50 ohms = 2.236 Vrms = 6.324 Vpp sine-equivalent
```

## 2. 第二步：建立新的 KiCad 工程副本

不要直接破坏原始 `bbb` 工程。复制出新工程：

```text
wspr_transceiver.kicad_pro
wspr_transceiver.kicad_sch
wspr_transceiver.kicad_pcb
```

建议做法：

1. 在文件管理器中复制 `bbb.kicad_pro`、`bbb.kicad_sch`、`bbb.kicad_pcb`。
2. 改名为 `wspr_transceiver.*`。
3. 用 KiCad 打开新 `.kicad_pro`。
4. 确认原 schematic 和 PCB 能正常打开。

完成标准：

- 原 `bbb.*` 保留不动。
- 新工程可以编辑。
- PCB outline 和 mounting holes 与原板一致。

## 3. 第三步：确定硬件架构

推荐你采用这个主方案：

```text
TX mode:
Si5351 CLK2
 -> input attenuator / DC block
 -> driver stage
 -> PA final stage
 -> harmonic cleanup / matching
 -> GPIO-controlled T/R switch
 -> shared BPF
 -> SMA 50 ohm output

RX mode:
SMA 50 ohm input
 -> GPIO-controlled T/R switch
 -> shared BPF
 -> original receiver chain
```

优先方案：

- PA：分立 transistor/MOSFET PA，目标输出 20 dBm。
- T/R switch：PIN diode switch 或合适的 RF switch。
- GPIO：新增 `TR_CTRL` 控制 TX/RX。
- PA enable：新增 `PA_EN`，保证 RX 时 PA off。

备用方案：

- 如果 PIN diode switch 调不顺，可使用小继电器或确认频率范围合适的 RF switch IC。
- 如果分立 PA 达不到 20 dBm，可使用 driver + final 两级，或换 RF transistor。

你需要在 report 中明确：

```text
TR_CTRL = 0: RX mode, PA off, SMA -> BPF -> RX
TR_CTRL = 1: TX mode, PA on, PA -> BPF -> SMA
```

## 4. 第四步：先做功率计算

作业要求：

```text
Pout = 0.1 W into 50 ohms
```

报告中必须写出：

```text
Pout = 0.1 W = 20 dBm
Rload = 50 ohms
Vrms = sqrt(P * R) = sqrt(0.1 * 50) = 2.236 V
Vpk = sqrt(2) * Vrms = 3.162 V
Vpp = 2 * Vpk = 6.324 Vpp
Irms = Vrms / R = 44.7 mA
```

设计目标建议：

- PA 设计能力留到约 `23 dBm`。
- 实际输出通过 bias、matching 或 attenuator 调到约 `20 dBm`。
- PA 后必须接 50 ohm dummy load 测试，不要直接接接收机。

## 5. 第五步：当天完成采购清单

采购必须来自 Element14 Australia。下单前当天重新确认库存、交期和 order code。

第一批优先买这些，不等 PCB 完成：

| 类别 | 数量建议 | 用途 |
|---|---:|---|
| PA final MOSFET / RF transistor | 每种 5-10 | 100 mW PA 原型和备件。 |
| RF driver transistor | 5-10 | 驱动 PA final。 |
| PIN diode | 每种 10-20 | 做 T/R switch。 |
| C0G/NP0 RF capacitor | 每值 10-20 | matching、filter、DC block。 |
| RF inductor | 每值 5-10 | PA 输出匹配和 LPF。 |
| 50 ohm / attenuator resistor | 每值 20 | 输入/输出衰减、dummy load、匹配。 |
| SMA connector / test point | 2-5 | RF 输入输出和测量点。 |

采购表必须记录：

```text
Part name
Manufacturer part number
Element14 order code
Package
Quantity
Unit price
Stock status
Estimated delivery date
Datasheet URL
Why selected
Backup part
Checked date
```

保存为：

```text
hardware_bom_element14.md
```

不要只买一个型号。PA final、PIN diode、RF switch 至少各保留一个备选。

## 6. 第六步：画 Part A RF loopback 修改

Part A 是现有板子的物理改造，用来让软件发射先能被接收机解码。

推荐电路：

```text
Si5351 CLK2
 -> 100 pF to 1 nF DC blocking capacitor
 -> resistive attenuator
 -> short coax / short wire
 -> receiver RF input before mixer/BPF chain
```

执行步骤：

1. 找到 `CLK2` test point 或 Si5351 `CLK2` 引脚附近可焊点。
2. 找到 `RFIN` 或 receiver RF input 可焊点。
3. 先设计较大衰减，不要直接连接。
4. 在纸上或 KiCad 中画出修改电路。
5. 焊接后拍照。
6. 用示波器测：
   - `CLK2` 直接输出幅度
   - 衰减后进入 receiver 的幅度
7. 把测量表放进报告。

完成标准：

- 有修改电路图。
- 有实物照片。
- 有测量数据。
- 能解释为什么不会过载 receiver input。

### 6.1 接收机过载不是 5 V / 3.3 V 逻辑不匹配

Part A 中说的 receiver overload，主要不是普通数字电路里的 `5 V -> 3.3 V` 逻辑电平不匹配，而是 **RF 输入幅度太大，超过接收机前端线性范围**。

示波器证据见：

```text
report_images/partA_clk_overload_scope.jpg
```

该截图显示 Si5351 相关时钟输出约：

```text
Frequency ~= 6.993 MHz
CH1 Vpp ~= 4.28 V
CH2 Vpp ~= 4.45 V
Phase ~= 89 deg
```

这类信号是 CMOS 方波时钟，幅度是“几伏 Vpp”等级；而 receiver RF input 期望的是弱 RF 信号，通常是 microvolt 到 millivolt 等级。把几伏方波直接接到 `RFIN` 或 `BPFIN`，会让后级饱和：

```text
RFIN / C2
 -> U1 THS4304 RF amplifier saturates
 -> RFOUT clips or becomes nonlinear
 -> U3 TS3A5017 mixer is overdriven
 -> I/Q audio distortion
 -> WSPR decoder cannot decode reliably
```

如果把 `4.3 Vpp` 粗略按正弦等效估算：

```text
Vrms = Vpp / (2 * sqrt(2))
     = 4.3 / 2.828
     ~= 1.52 Vrms

P50 = Vrms^2 / 50
    ~= 1.52^2 / 50
    ~= 0.046 W
    ~= +16.6 dBm
```

`+16.6 dBm` 对接收机输入来说非常强。WSPR receiver 的 RF input 应从很小电平开始测试；Part A loopback 只需要 decoder 能解码，不需要大功率。

### 6.2 电压不匹配和 RF 过载的区别

| 问题 | 发生位置 | 结果 | Part A 关注点 |
|---|---|---|---|
| 5 V / 3.3 V 逻辑不匹配 | 数字 GPIO / digital input | 可能损坏 3.3 V 逻辑输入 | 不要把 5 V digital signal 直接接 3.3 V pin。 |
| RF receiver overload | `RFIN`, `BPFIN`, U1/U3 analog RF path | 放大器/mixer 饱和，解码失败，严重时可能损坏输入 | `CLK2` 必须先隔直和大幅衰减。 |

本项目 Part A 的核心问题是第二类：`CLK2` 是 RF 方波源，但 receiver input 是敏感模拟 RF 输入。即使 `CLK2` 是 3.3 V CMOS，也仍然远大于接收机需要的 RF 电平。

### 6.3 安全的 Part A 衰减起步值

第一次 RF loopback 不要直接连接：

```text
CLK2 -> RFIN
```

推荐从大衰减开始：

```text
CLK2
 -> 100 pF to 1 nF DC blocking capacitor
 -> 10 kΩ series resistor
 -> injection point: RFIN_TP7 or BPFIN
        |
       50 Ω or 100 Ω
        |
       GND
```

若使用 `10 kΩ + 50 Ω` 分压：

```text
Voltage ratio = 50 / (10000 + 50)
              ~= 0.005
Attenuation   ~= -46 dB

4.3 Vpp -> about 21 mVpp
```

若使用 `10 kΩ + 100 Ω` 分压：

```text
Voltage ratio = 100 / (10000 + 100)
              ~= 0.0099
Attenuation   ~= -40 dB

4.3 Vpp -> about 43 mVpp
```

调试顺序：

```text
10 kΩ series first
 -> if too weak, try 4.7 kΩ
 -> then 2.2 kΩ
 -> then 1 kΩ
```

每次只减少一级衰减，并观察 receiver 是否出现饱和、削顶、audio distortion 或 decoder 失败。

### 6.4 已验证参考输入：30 mVpp

之前实验中接收机使用过的参考 RF 输入为：

```text
report_images/partA_30mVpp_reference_input.jpg

Function generator:
receiver frequency = 7.0386 MHz
amplitude = 30.000 mVpp
offset    = 0 V
load mode = High-Z
waveform  = sine
```

把这个值作为 Part A RF loopback 的首选目标注入电平：

```text
Target receiver injection level ~= 30 mVpp
```

注意 `High-Z` 设置的含义：函数发生器屏幕上的 `30 mVpp` 是按高阻负载显示的。如果把函数发生器直接接到 50 ohm termination，实际电压可能约减半。Part A loopback 中应以示波器在 `RFIN_TP7` 或 `BPFIN` 处实际测到的 Vpp 为准。

### 6.5 从 Si5351/CLK2 反推所需衰减

示波器测得未衰减 Si5351 clock 约：

```text
CLK Vpp ~= 4.3 Vpp
```

目标接收机输入：

```text
Vtarget = 30 mVpp = 0.030 Vpp
```

所需电压比例：

```text
ratio = Vtarget / Vclk
      = 0.030 / 4.3
      ~= 0.00698
      ~= 1 / 143
```

换算为 dB：

```text
attenuation_dB = 20 * log10(0.00698)
               ~= -43.1 dB
```

所以从 `CLK2` 到 receiver input 需要约 `43 dB` 的电压衰减，才能把几伏方波压到约 `30 mVpp`。

如果按 50 ohm 等效输入计算 `30 mVpp` 对应功率：

```text
Vrms = Vpp / (2 * sqrt(2))
     = 0.030 / 2.828
     ~= 10.6 mVrms

P50 = Vrms^2 / 50
    ~= 2.25 uW
    ~= -26.5 dBm
```

这个电平仍然比真实空中 WSPR 弱信号大很多，但作为硬线 loopback/debug 输入是合理的起点，因为你们已经用函数发生器验证过接收链可处理 `30 mVpp`。

### 6.6 用电阻实现 30 mVpp 目标

使用一个隔直电容、一个串联电阻和一个明确的 shunt resistor，可以让输入电平可预测：

```text
CLK2
 -> 100 pF to 1 nF DC blocking capacitor
 -> Rs
 -> injection point: RFIN_TP7 or BPFIN
        |
       Rsh
        |
       GND
```

公式：

```text
Vout = Vin * Rsh / (Rs + Rsh)

Rs = Rsh * (Vin / Vout - 1)
```

若 `Vin = 4.3 Vpp`、`Vout = 30 mVpp`：

| Shunt resistor `Rsh` | Calculated `Rs` | Practical choice | Expected Vout |
|---:|---:|---:|---:|
| 50 ohm | 7.1 kΩ | 6.8 kΩ | about 31 mVpp |
| 50 ohm | 7.1 kΩ | 7.5 kΩ | about 28 mVpp |
| 100 ohm | 14.2 kΩ | 15 kΩ | about 28 mVpp |
| 235 ohm approximate receiver load | 33.4 kΩ | 33 kΩ | about 30 mVpp |

推荐实际起步：

```text
CLK2 -> 1 nF -> 6.8 kΩ -> RFIN_TP7
                         |
                        50 Ω
                         |
                        GND
```

这会把 `4.3 Vpp` 降到约 `31 mVpp`，非常接近之前实验的 `30 mVpp`。如果担心过载，先用 `10 kΩ + 50 Ω` 得到约 `21 mVpp`，确认接收链没有削顶后再换成 `6.8 kΩ`。

若只用串联电阻、不加明确 shunt resistor，输出电平会依赖接收机输入阻抗。图中 `RFIN` 经 `C2` 后看到的偏置网络大约包含 `R1 || R3 = 470 Ω || 470 Ω ~= 235 Ω`，但实际还会受 BPF、测试点、探头和布线影响。因此报告里更推荐写明使用了外部 `50 Ω` 或 `100 Ω` shunt 来固定衰减比。

### 6.7 推荐测量点和判断标准

示波器测量时：

- 优先使用 `10x probe`，减少探头对 RF 节点的负载。
- 先测 `CLK2` 原始输出，再测衰减后的注入点。
- 注入点可以先选 `RFIN_TP7`，成功后再换到 `BPFIN` 或 SMA，让信号经过 BPF。
- 保持短地线或用短同轴，避免测到过多 ringing。

记录表：

| 测量点 | 记录内容 | 判断 |
|---|---|---|
| `CLK2` | frequency, Vpp, waveform | 证明 TX source 存在。 |
| attenuator output | Vpp after attenuation | 确认不是几伏直接进 receiver。 |
| `RFIN_TP7` | injected RF level | 先从 tens of mVpp 或更低开始。 |
| `RFOUT_TP8` | U1 output waveform | 不应明显削顶/贴 rail。 |
| audio I/Q output | Iout/Qout waveform | 不应严重削顶，decoder 应能看到 tone。 |

报告写法：

```text
Receiver overload was avoided by treating the Si5351 CLK2 output as a large
CMOS RF waveform, not as a small antenna-level signal. A DC blocking capacitor
and resistive attenuator were inserted before RFIN/BPFIN. The unattenuated
clock was about 4.3 Vpp at 6.993 MHz, so the first loopback tests used about
40-46 dB attenuation before injecting the signal into the receiver input.
```

## 7. 第七步：画 Part B 新原理图

在 `wspr_transceiver.kicad_sch` 中新增或修改这些模块。

### 7.1 TX input from Si5351

新增网络：

```text
CLK2 -> TX_RF_RAW -> C_DC_BLOCK -> R_ATTENUATOR -> TX_PA_IN
```

要求：

- `CLK2` 后加 DC blocking capacitor。
- 加一个可调/可改值 attenuator，避免 PA input 过驱。
- 加 test point：`TP_CLK2_TX`、`TP_PA_IN`。

### 7.2 PA driver + final

新增网络：

```text
TX_PA_IN -> driver -> PA_FINAL -> TX_PA_OUT
```

要求：

- 明确 bias resistor。
- 电源旁边放 `100 nF + 1 uF/10 uF` 去耦。
- `PA_EN` 控制 PA 供电或偏置。
- 输出端预留 matching network：

```text
series L / shunt C / pi network / DNP footprints
```

### 7.3 Harmonic cleanup

在 PA 后加：

```text
TX_PA_OUT -> LPF or matching/filter network -> TX_FILTERED
```

如果你认为共享 BPF 已足够，也要在报告中解释。但 PCB 上建议预留 DNP 的 LPF 位，方便调试。

### 7.4 T/R switch

新增网络：

```text
TX_FILTERED -> T/R switch -> shared BPF -> SMA
SMA -> T/R switch -> shared BPF -> RX_CHAIN
```

要求：

- `TR_CTRL` 控制 TX/RX。
- 默认状态建议 RX。
- TX 时 RX input 必须隔离或保护。
- RX 时 PA 必须关闭。

### 7.5 Test points

至少加：

```text
TP_CLK2_TX
TP_PA_IN
TP_PA_OUT
TP_TR_CTRL
TP_PA_EN
TP_ANT_50R
TP_RX_IN
```

## 8. 第八步：PCB layout 执行顺序

layout 不要从漂亮开始，从 RF 关键路径开始。

执行顺序：

1. 锁定原板 outline、mounting holes、SMA 位置。
2. 先放 T/R switch，靠近 BPF 和 SMA。
3. 再放 PA final，靠近 T/R switch，但和 RX input 保持距离。
4. 放 PA driver，靠近 PA final。
5. 从 Si5351 `CLK2` 到 `PA_IN` 走线尽量短。
6. PA 输出到 switch/BPF/SMA 走线尽量短、少过孔、少 stub。
7. PA 电源线加宽，去耦电容贴近 PA 管脚。
8. RF path 下方尽量保持连续 ground。
9. 增加 ground vias，尤其是 PA、switch、SMA 附近。
10. 最后再放 test points 和丝印。

PCB 检查：

- 板框尺寸不变。
- 新增器件 footprint 与 datasheet land pattern 一致。
- TX PA output 不要长距离贴着 RX input 走。
- `TR_CTRL` 和 `PA_EN` 不要从 RF 线旁边长距离平行走。
- 50 ohm RF 线尽量短；如果不能精确控阻，也要避免长线和突变。

## 9. 第九步：ERC/DRC 和制造文件

KiCad 中执行：

1. Schematic ERC。
2. Update PCB from schematic。
3. PCB DRC。
4. Plot Gerbers。
5. Generate drill files。
6. Export BOM。
7. Export placement/position file。

需要保存：

```text
fabrication/gerbers/
fabrication/drill/
fabrication/bom/
fabrication/position/
report_images/pcb_top.png
report_images/pcb_bottom.png
report_images/pcb_3d.png
```

DRC 如果有错误：

- 能修就修。
- 不能修的写进 `hardware_known_issues.md`，说明原因。

## 10. 第十步：硬件 bring-up 测试

不要第一次上电就直接 TX 100 mW。

顺序：

1. 不焊 PA final，测电源。
2. 测 `TR_CTRL` 和 `PA_EN` GPIO 电平。
3. 焊 T/R switch，测 RX path 是否通。
4. 焊 driver，测 `TX_PA_IN` 和 driver output。
5. 焊 PA final，限流供电。
6. PA 输出先接：

```text
20 dB attenuator -> 50 ohm dummy load
```

7. 测输出电压，换算功率。
8. 达到接近 20 dBm 后，再接 shared BPF。
9. 测 TX/RX 切换：
   - RX mode：PA off，SMA -> BPF -> RX
   - TX mode：PA on，PA -> BPF -> SMA
10. 最后再和软件发射/decoder 联调。

输出功率换算：

```text
P = Vrms^2 / 50
dBm = 10 * log10(P / 1 mW)
```

如果测的是 Vpp：

```text
Vrms = Vpp / (2 * sqrt(2))
```

## 11. 报告中你负责放的内容

硬件部分报告必须有：

- Part A RF loopback 修改电路图。
- Part A 修改后 PCB 照片。
- `CLK2` 输出和 receiver input 的实测电平。
- Part B 完整 TX/RX signal path 图。
- PA 输出 `0.1 W into 50 ohms` 计算。
- PA 原理图和关键元件值。
- T/R switch 原理图。
- GPIO truth table。
- PCB top/bottom layout 截图。
- Element14 BOM 表。
- ERC/DRC 状态说明。

GPIO truth table 可直接用：

| `TR_CTRL` | `PA_EN` | 模式 | RF path |
|---|---|---|---|
| 0 | 0 | RX | SMA -> T/R switch -> shared BPF -> receiver |
| 1 | 1 | TX | CLK2 -> PA -> T/R switch -> shared BPF -> SMA |

## 12. 你每天结束前要提交的东西

每天至少更新一次：

```text
hardware_decision_log.md
hardware_bom_element14.md
hardware_known_issues.md
```

每天 Git 提交：

```powershell
git add .
git commit -m "Update hardware design progress"
git push
```

建议每次 commit message 写具体一点，例如：

```powershell
git commit -m "Add PA and TR switch schematic draft"
git commit -m "Add Element14 hardware BOM"
git commit -m "Route transmitter RF path"
git commit -m "Add PCB screenshots for report"
```

## 13. 最容易扣分的点

- 只画了 PA，没有说明 TX/RX 如何共用 BPF。
- 只写了 0.1 W，没有给 `50 ohm` 电压/电流计算。
- TX 时没有保护 RX input。
- GPIO 只写“控制”，没有 truth table。
- 新器件没有 Element14 order code。
- PCB 尺寸改变了。
- 报告解释了太多旧 WSPR-SDR，反而没解释你的新增设计。

## 14. 最小可交付版本

如果时间不够，最低也要完成：

1. 新 KiCad 工程。
2. `CLK2 -> PA -> T/R switch -> shared BPF -> SMA` 原理图。
3. `SMA -> T/R switch -> shared BPF -> RX` 原理图。
4. 0.1 W / 50 ohm 计算。
5. Element14 BOM。
6. PCB 保持原尺寸，并放置/连接所有新增模块。
7. ERC/DRC 记录。
8. Part A RF loopback 修改图和照片。

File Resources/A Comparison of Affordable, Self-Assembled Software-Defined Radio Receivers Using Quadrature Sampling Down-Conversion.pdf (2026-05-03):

A Comparison of Affordable, Self-Assembled Software-Defined Radio Receivers Using Quadrature Sampling Down-Conversion

Caleb Froelich
Dr. Rob Frohne, KL7NA
Konrad McClure
Joshua Silver
Jordyn Watkins, KN6FFS

Walla Walla University

ABSTRACT

The software-defined radio (SDR) is a low-cost radio with the potential to draw attention from both experienced and inexperienced operators. As part of a class project, we designed and built quadrature sampling down-conversion SDR receivers. With the receivers we built and the resulting knowledge from that experience, we wanted to contribute to the impact SDR receivers have on growing the amateur radio community. This paper describes the quadrature sampling detector (QSD) in an easy to understand manner, analyzes the advantages and disadvantages of four different SDR receiver designs, and presents a design guide to building an SDR receiver with relevant equations and considerations.

INTRODUCTION

As the future of the world is uncertain amidst the COVID-19 pandemic, the future of amateur radio is equally uncertain. Noting the majority of ham radio operators are in their 60s and 70s and the growth of the number of new amateur radio licenses has held constant at 1% for the past few years, it appears that the pertinent questions are “How do we attract younger operators?” and “How will this younger generation change the course of amateur radio?

i
” Ham radio has already been changed significantly by the introduction of low-cost radios. Handheld VHF/UHF transceivers like those made by Baofeng are affordable and easy to use. And now software-defined radios (SDRs) are bringing that same budget price tag to HF.ii

Low-cost is not the only reason SDRs have become more popular among the amateur radio community. More recently, Guido Ten Dolle’s µSDX open source transceiver has generated increasing interest in quadrature sampling down-conversion SDRs in the homebrew QRP community. Guido, PE1NNZ, was able to modify the QCX, QRP transceiver for SSB operation with an efficient class-E amplifier, using only an ATMEGA328 and Arduino code to run the QSD SDR. This groundbreaking work in this type of SDR has inspired various renditions of Guido’s radio, fostering a lively groups.io group that can be followed at https://groups.io/g/ucx.

For our Electronics II class at Walla Walla University, we designed, built, and tested SDR receivers with the primary goal of furthering our education in electronic engineering concepts while remaining within a $25 budget. Although we had the privilege of many hours of dedicated class time for researching and designing an SDR receiver, we recognize not everyone has this same opportunity. We resolved to compose an easy to understand explanation of quadrature sampling detectors (QSDs), (the heart of the type of SDR we all designed), provide a comparison of our SDR receivers with an emphasis on aspects in the designs that enhance or diminish performance, as well as provide a design guide to quadrature sampling down-conversion software-defined receivers with design tools, resources, and tips. This information can help flatten the learning curve in addition to supplementing hobbyist interests in this type of SDR, such as Guido Ten Dolle’s µSDX transceiver.

FUNDAMENTAL INFORMATION

The fundamental ideas pertinent to QSD SDR radios, especially the four presented designs, are the operation of mixers and the use of quadrature signals. This section will cover each in an accessible level of detail.

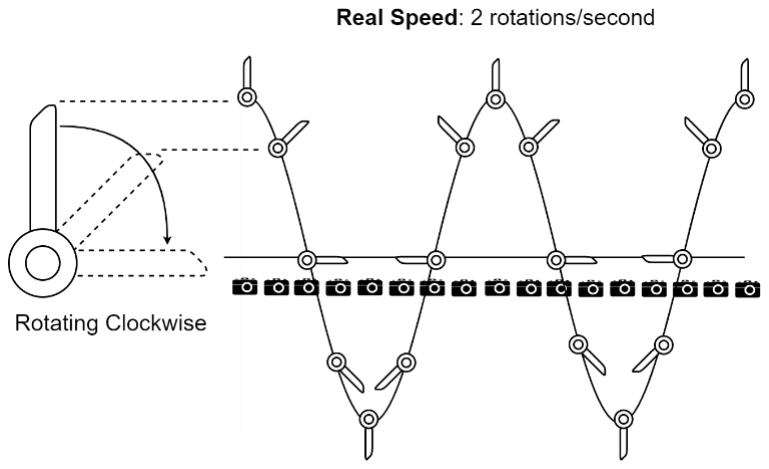
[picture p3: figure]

The goal of the mixer is to sample the input
from the antenna for information. To start with a simple analogy, have you ever seen a video where a plane propeller starts up? If so, you have likely noticed it appears to spin in one direction, slow down until stationary, and then spin in the reverse direction. This phenomenon is useful to explain mixers. Imagine we have a propeller that is spinning, and a camera is set up to take snapshots of the propeller as it spins.

As a visual example, Figure 1 shows a plot that traces only the vertical height of the tip of one blade of the propeller over time as it
spins | clockwise | at | a | rate | of | 10
rotations/second. The line traces the true position, while the small images of the propeller blade along it shows what would be seen if an image was taken at that moment. In this case, the camera is taking pictures at a rate 8 times faster than the blade rotation rate.

To continue the example, if pictures are taken at the same time the propeller makes one full rotation, as shown in Figure 2, it will appear stationary as if the propeller is
not spinning at all.

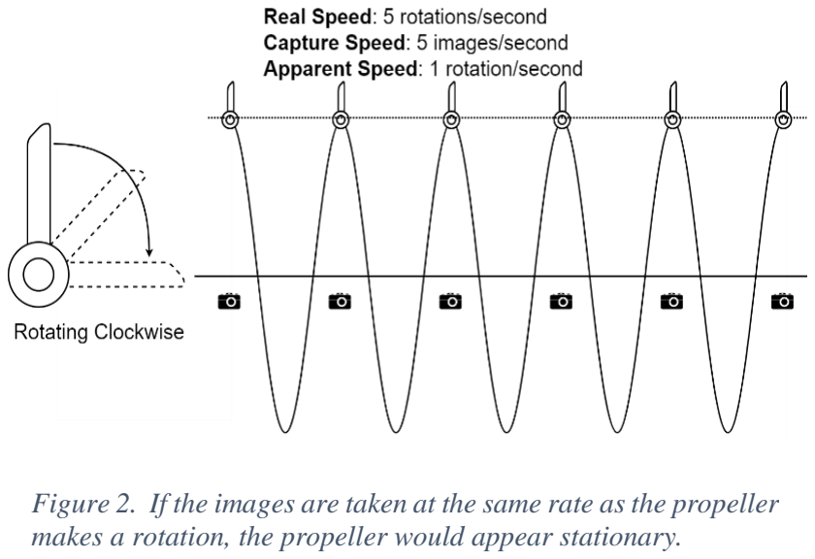
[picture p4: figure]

If pictures are taken at a rate slightly slower than the rotation rate of the propeller, like in Figure 3, the images will show the propeller slowly turning in the same direction. Conversely, if pictures were taken faster than the rotation rate of the propeller, like in Figure 4, the images would show

Figure 1. Vertical position of the tip of one propeller blade tracked via pictures taken at 8x the rate of rotation.

Figure 2. If the images are taken at the same rate as the propeller makes a rotation, the propeller would appear stationary.

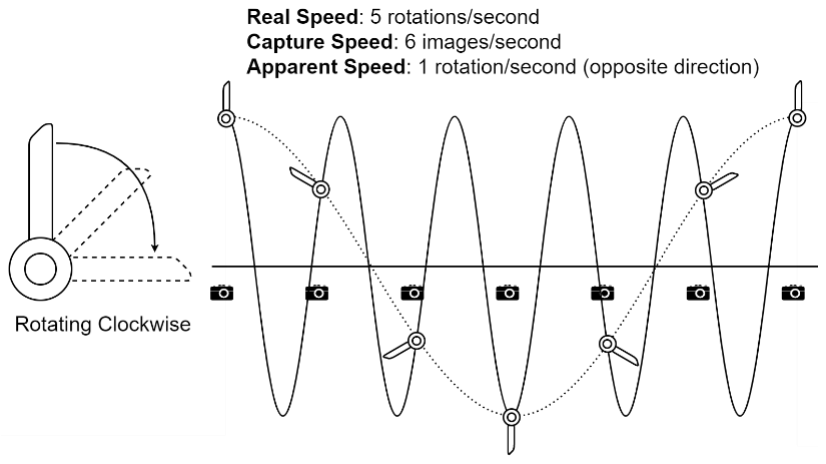
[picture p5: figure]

the propeller slowly turning in the opposite direction. Interestingly, the trace of the height of the propeller tip is
identical | despite | the | propeller
apparently turning in reverse.
By | taking | snapshots | you | have
effectively | changed | the | apparent
frequency of rotation to be the difference between the frequency of rotation of the propeller and the frequency of snapshots taken.

As can be seen in the examples above, the frequency of the apparent rotation is equal to (real speed — capture speed). If the capture speed is faster than the real speed, the difference is negative, indicating the propeller will appear to be turning in the opposite direction. All three cases occur when a video is taken of a propeller, though it is the framerate of the video remaining constant while the propeller increases in speed.

The frequency of rotation of the propeller is like the frequency of the radio signal (“RF signal” with frequency
“fRF”) you wish to tune to. The
frequency of the snapshots is the

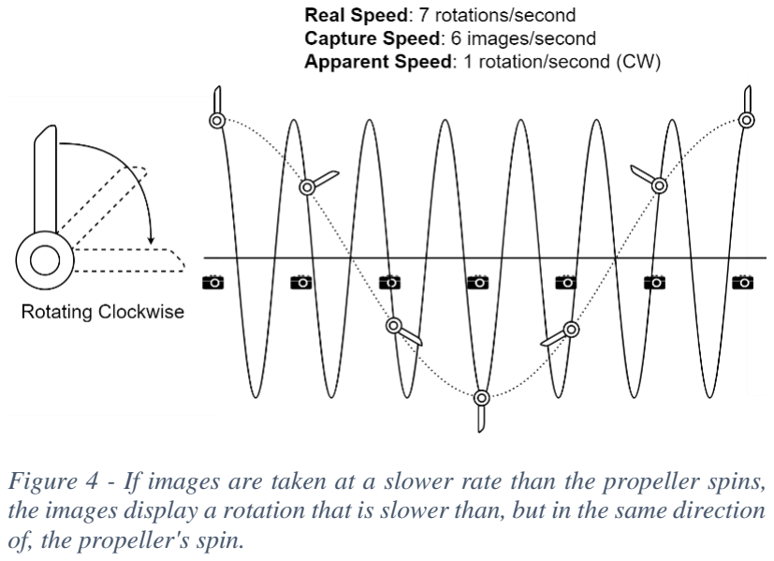
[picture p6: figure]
of, the propeller's spin.

frequency you can control. This frequency is generated by a clock, known as the local oscillator (“LO signal” with frequency “fLO”). This turns our apparent rotation speed equation from (real speed — capture speed) into (fRF − fLO). The local oscillator is used to time the switches that take the “snapshots” used to slow down the frequency of the signal you wish to listen to down to a frequency slow enough for your sound card and computer to process. The classic example of an ideal mixer at first appears to be different than the propeller blade analogy, will output both a difference frequency (fRF − fLO) as well as a sum frequency (fRF + fLO). In the example to the right in Figure 5, a 10 MHz RF signal is mixed with a 9.99 MHz LO signal to produce two frequencies: (fRF − fLO) = 10kHz and (fRF + fLO) = 19.99 MHz. The slow 10kHz signal is the desired

Figure 4 - If images are taken at a slower rate than the propeller spins, the images display a rotation that is slower than, but in the same direction

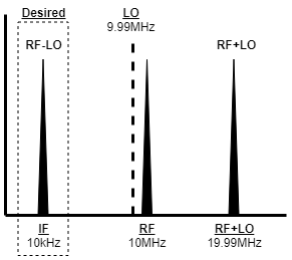
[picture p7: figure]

Figure 5. To down-convert a received signal to a slower frequency, the Radio Frequency (RF) and Local Oscillator (LO) frequencies are mixed, resulting in a new Intermittent Frequency (IF)

Figure 3. If the images are taken at a faster rate than the propeller spins, the images display a rotation that is slower than, but in the opposite frequency since the sound card can process it. The 19.99 MHz signal is easily filtered out with a low-pass filter due to its distance from the desired 10kHz frequency. The mixer circuitry used in all the following designs expand on the classic example somewhat by including sampling capacitors on the output, which keep the sampled voltages like the film stores the snapshots of the camera. These capacitors create a low-pass filter that will smooth out the instantaneous points captured into a continuous curve as illustrated in the figures of this section. In the same way, by the
nature of the human brain, we assume that
between each snapshot is a smooth

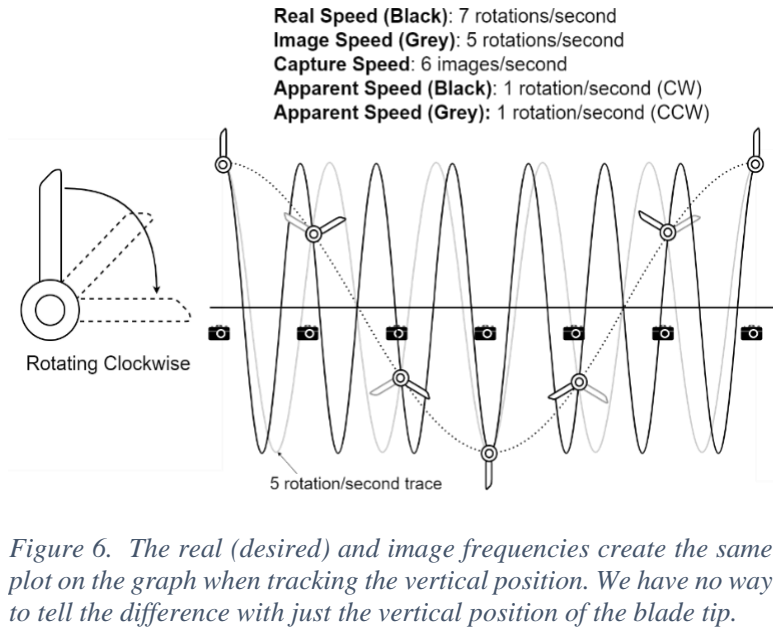
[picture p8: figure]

transition between the two positions, which results in that same continuous “apparent” trace that the low-pass filter creates.

A key detail of the slower and faster rate examples is that the apparent rates of the propeller both have the same 1 rotation/second rate and produce the exact same trace on the graph. The only difference between them is the direction of rotation. The two are superimposed together in Figure 6 with the faster rate in black and the slower rate in grey. Unfortunately, there is a key difference between our analogy of taking pictures of rotating propeller and the reality of radio mixers. We are able to identify the direction of apparent rotation from these graphs through the little images of the propeller along the trace of the vertical position. If we only had a plot of the apparent vertical position, however, it would be impossible to tell which direction it was rotating. The two rates, 5 rot/sec and 7 rot/sec are referred to as “images” of each other.

In terms of radio signals and the previous radio example, our desired RF signal would be the 10MHz signal would be down-converted by the 9.99MHz LO frequency to a positive (“CW”) 10kHz. However, as shown in Figure 7, if there was a
second frequency broadcasted at 9.98MHz, that is the same
distance from LO as our desired RF (this frequency would
be referred to as the Image), the Image would also get down-converted to 10kHz IF frequency, except the Image is negative (“CCW”). As a result, we would hear both broadcasts from the speakers.

The solution in the propeller example is to track both the horizontal and vertical positions of the tip simultaneously, which previously was done artificially by including the small propeller images along the trace. If instead two axes are created to track them simultaneously, the direction of rotation can be determined. Figure 8 and Figure 9 display this on the following page.

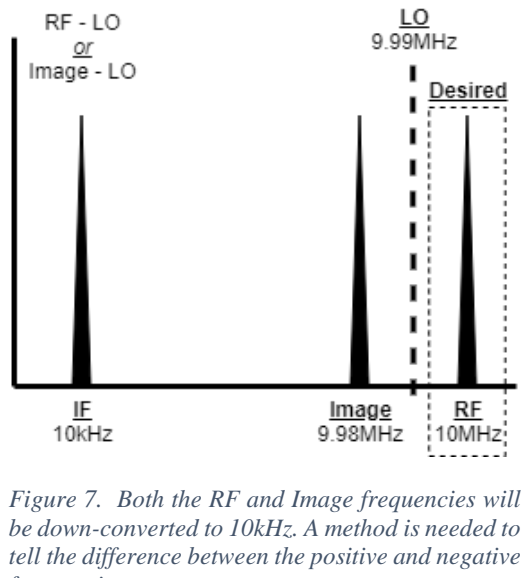
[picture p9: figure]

Figure 7. Both the RF and Image frequencies will be down-converted to 10kHz. A method is needed to tell the difference between the positive and negative

Figure 6. The real (desired) and image frequencies create the same plot on the graph when tracking the vertical position. We have no way to tell the difference with just the vertical position of the blade tip.

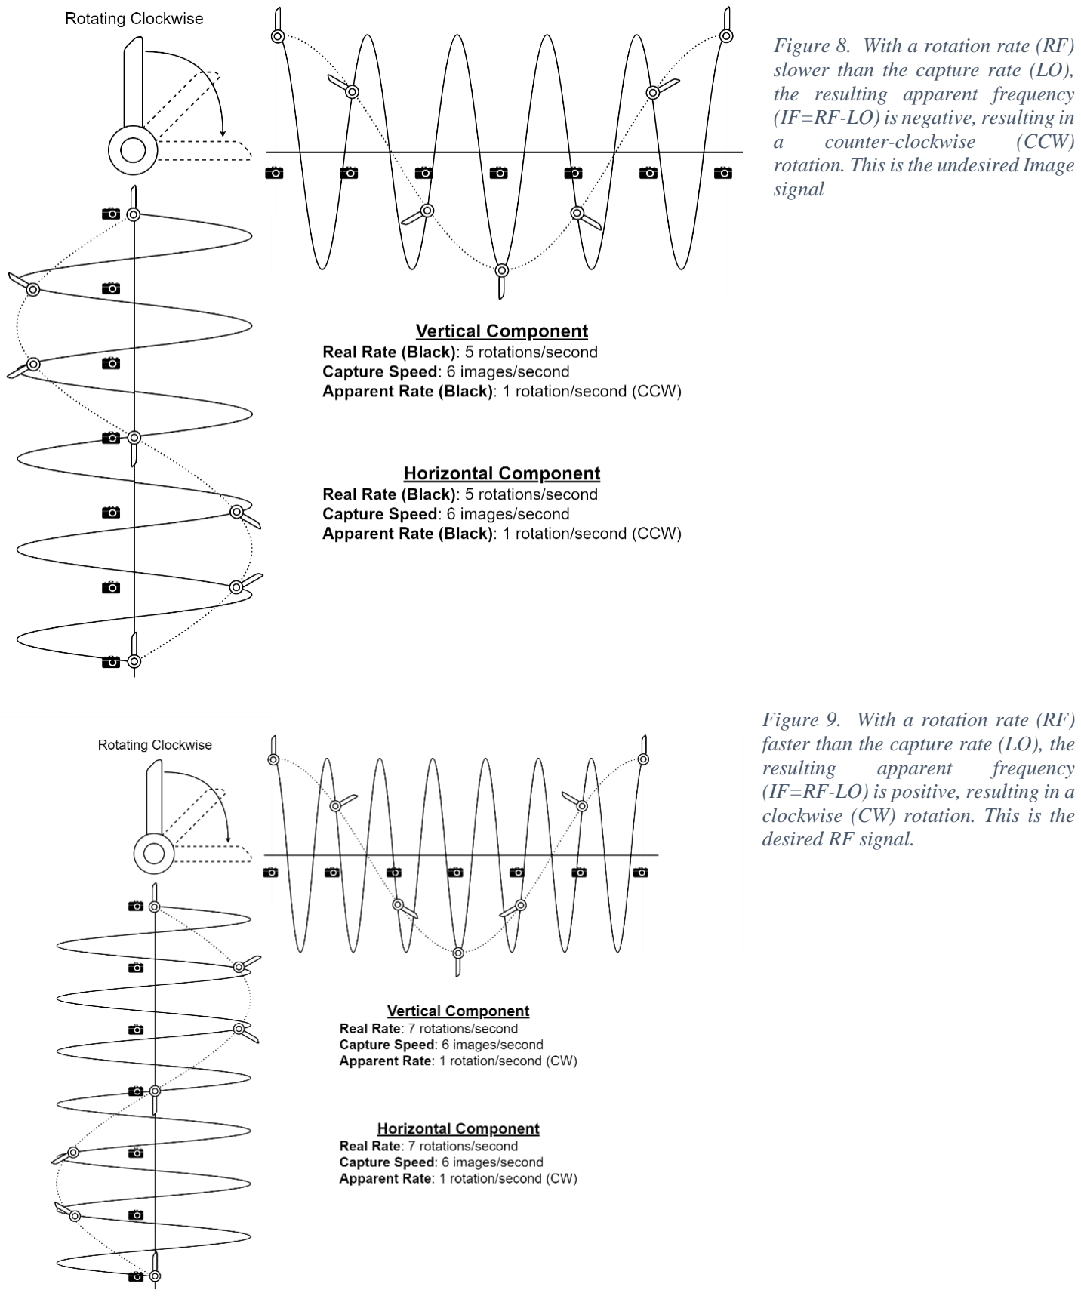
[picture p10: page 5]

Figure 8. With a rotation rate (RF) slower than the capture rate (LO), the resulting apparent frequency (IF=RF-LO) is negative, resulting in
a | counter-clockwise | (CCW)
rotation. This is the undesired Image signal

Figure 9. With a rotation rate (RF) faster than the capture rate (LO), the
resulting | apparent | frequency
(IF=RF-LO) is positive, resulting in a clockwise (CW) rotation. This is the desired RF signal.

With this, we introduce what are known as Quadrature signals. In their most simple explanation, Quadrature signals are signals that are 90° (quarter of a cycle) out of phase with each other. Examining Figures 8 and 9, we can
see that Figure 8 produces a CCW
output while Figure 9 produces a
CW output. Looking closer, we see that while the vertical positions trace
the | same | path | as | previously
observed, the horizontal positions are
reflected | across | the | axis.
Superimposing these two axes from the vertical and horizontal positions, as shown in Figure 10, we can easily see how the “clockwise-ness” is determined. On a positive frequency, the propeller reaches the “upmost position” a quarter of a cycle before
the | “rightmost | position.”
Conversely, on a negative frequency, the propeller reaches the “rightmost position” a quarter of a cycle before the “upmost position.” Since the vertical trace remains constant no matter the sign of the frequency, it is referred to as the In-Phase (I) signal. It is used as a reference point to compare the horizontal trace to, known as the Quadrature (Q) signal. Another illustration of this is seen in Figure 11, where each scenario has been superimposed.

Back to our example in Figure 7, the Image signal at negative 10kHz can now be ignored by the software processing the digital signal from the soundcard if it is provided with both the I and Q components of the signal. Often, this can be done with two mixers: one that produces the I signal, and another that produces the Q signal. This kind of configuration can be seen in Design 3 using two
voltage-controlled | switches | as
mixers. Another method, as can be seen in Designs 1, 2, and 4, is to use

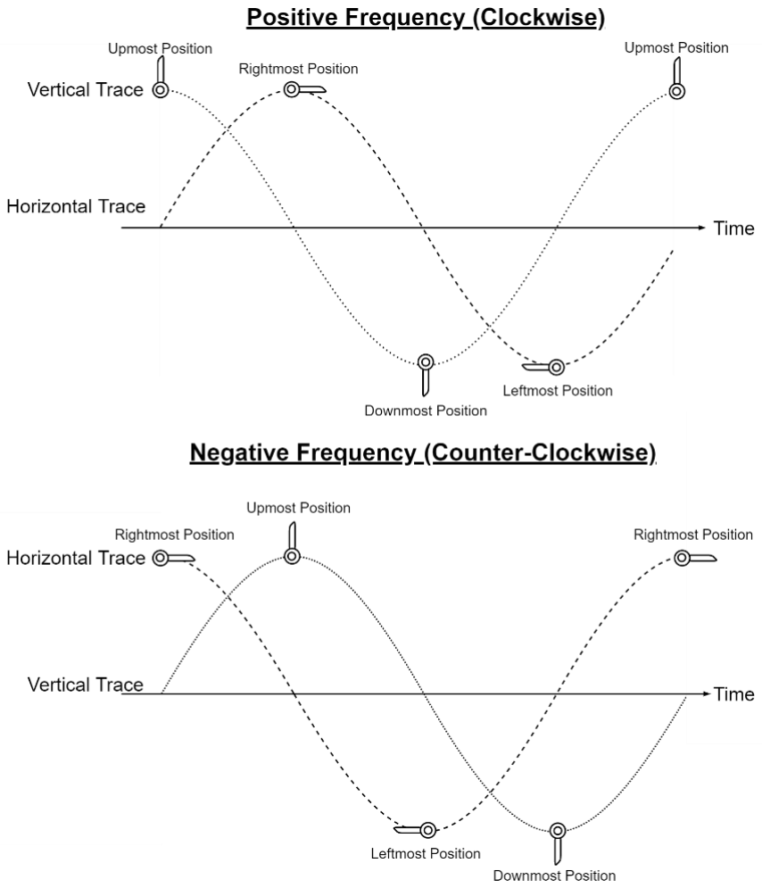
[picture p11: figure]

Figure 10. As time goes on, a positive (CW) frequency will reach the upmost,
rightmost, | downmost, | and | leftmost | positions | in | that | order.
A negative frequency will cycle through the rightmost, upmost, leftmost, and downmost positions in that order. This allows us to identify whether the quadrature signals represent a positive or negative frequency.

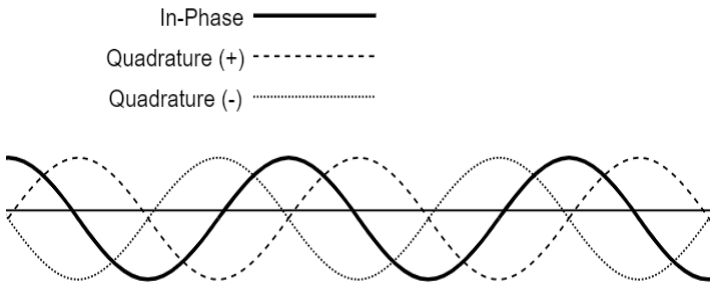
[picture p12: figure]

Figure 11. The In-Phase, Negative Quadrature, and Positive Quadrature signals superimposed to show the phase difference between them. Both quadrature signals are measured relative to the constant In-Phase signal.

a Quadrature Sampling Detector such as a Tayloe Detector, which converts the input into the I and Q signals directly.

There is one more issue to consider.
Returning to the RF equals LO example in Figure 2 where the
propeller | appears | stationary,
consider if the propeller is rotating at twice the rate of the snapshots. It will also appear to be stopped, just as if it had been rotating at the same rate. After some thought, you’d come to realize this is true for any integer multiple (2x, 3x, 4x, …) of the frequency, as shown in Figure 12. Evidently, there are an infinite number of rotation rates that can cause any apparent slow rotation rate you might guess by just looking at the snap shots. The same trace will match any frequency of f = freal + n × fcapture where n is any integer, as can be seen in Figure 13. Since any value of n will result in the same down-converted trace on both the vertical and horizontal axis.

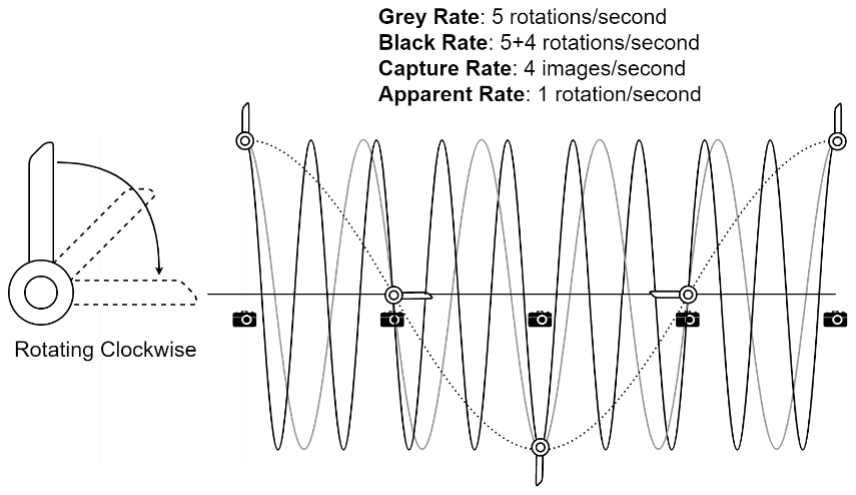
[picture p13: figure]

We only want our system to respond to rotation rates very close to the local oscillator frequency (the 5 rot/sec), not to every harmonic of the local oscillator (the 9 rot/sec, etc.). We want to translate the frequencies very near the local oscillator (around 4 rot/sec) down to near DC and keep
only those, not the others (near 8
rot/sec, etc.). If there are no

responses to these other frequencies, we can use a low pass filter to smoothly connect the sampling points and keep the desired band of frequencies near the local oscillator, now translated down to DC, and be done. These undesired responses, however, are a problem.

Similar undesired parasitic responses also occur in a radio receiver using instantaneous sampling like in the camera analogy (for both I and Q downconverters). The effect is undesired, because you want to listen to one and only one radio station at once. You want to remove all signals except the desired one near the local oscillator frequency. A key to solving this problem in QSD receivers is realizing the frequency conversion or sampling process is actually weighting (multiplying) the

Figure 12 - The propeller appears stationary at freal + 0 × fcapture, = 2

rot
sec

,freal + 1 × fcapture, = 4

rot
sec

, and freal + 2 × fcapture, = 8

rot
sec

Figure 13 - The apparent rate of the propeller can match freal +

signal by a time varying periodic function. The frequency of this local oscillator weighting function is just the number of Hertz we wish to shift the signal down. Because the weighting function is periodic, it is made up of a fundamental, and usually has harmonics. In the snapshot method, the weighting function is a series of very high short pulses, one at each shutter time when the photos are taken, and zero in between, where the shutter is closed on the camera. Each harmonic component in this weighting function is every bit as big as its fundamental frequency component. The undesired responses come from the harmonics shifting undesired signals down too, right on top of our desired signal. The ideal weighting function would have no harmonics at all, just a single sinusoid at the local oscillator frequency.

Unfortunately, multiplying by a time varying sinusoid in analog electronics is difficult, so it is common to use switches controlled by the local oscillator clock to create a periodic stepped weighting function instead. A simple example of this kind of weighting function is a square wave. The weighting function is selected to have less harmonic content than the snapshot method, thus reducing the undesired responses. It should be noted that sometimes we cannot create a weighting function with a high enough frequency, and in those cases, a harmonic (instead of the fundamental) can be used to down-convert the desired signal to audio frequencies. To really ensure the undesired RF signals do not get through, they are filtered out with bandpass filters before they reach the down conversion stage. If they are not present, we don’t have to worry about them interfering with the desired signal, even if using the “snapshot” weighting function.

A single pole single throw (SPST) switch connected to the RF signal multiplies it by one when closed, and zero when open. A center tapped transformer creates, on the secondary, both plus the RF signal and minus the RF signal. A single pole double throw (SPDT) switch controlled by the local oscillator clock accomplishes the multiplication by the square wave weighting function by selecting alternately one or the other. This method is used in Design 3, as shown in Figure 14. (Designs 1 through 4 are described in the next major section.) Sometimes amplifiers are used with the switches instead of transformers to set the levels of the segments of the stepped weighting functions. Designs 1, 2 and 4 use this approach.

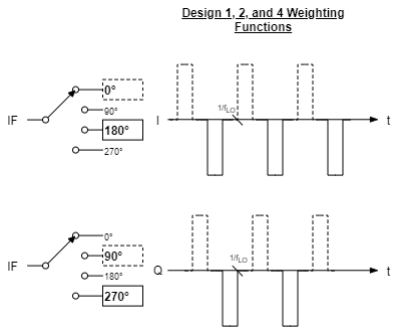
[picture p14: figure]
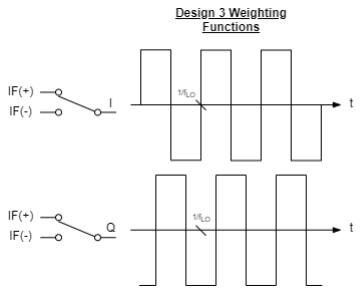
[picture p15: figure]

Figure 14 - Weighting function used by Design 3. | Figure 15 - Weighting function used by Designs 1 and 2. Design 4 is nearly identical, but the positive pulses are slightly taller

In the figure above, the weighting functions for the simple mixer and the Tayloe down converter are shown. It should be noted that all these waveforms have no even harmonics, and the odd harmonics all fall off as 1/m, where m is the harmonic number, which means the harmonics are dropped by using them, but not as far as you probably want. To really eliminate the undesired responses, a bandpass filter at the input which only allows the desired band of frequencies in, filtering out the harmonics, is the solution. To ensure only the output connects the smoothest function through the samples and the desired band of low frequencies which was shifted down remain in the result, we filter it with low pass filters, consisting of at least the sampling capacitor, and often further audio filters in subsequent stages.

Designs 1 and 2 use the Tayloe mixer weights shown in Figure 15, and Design 3 uses the square wave weighting, while Design 4 uses the Tayloe mixer with a circuit where the 0º and 90º signals are weighted slightly more than the 180º and 270º signals because of the amplifier gains in that circuit. Thus, upon close examination, that circuit would have very slightly higher positive going pulses, but the effect is too small to be visible on this scale.

DESIGN ANALYSIS AND COMPARISONS

We have four SDR receivers from which we will evaluate and compare the designs and draw conclusions. One was designed by Caleb Froelich and Konrad McClure (Design 1), a second by Joshua Silver and Jordyn Watkins (Design 2), and the third and fourth radios were designed by Rob Frohne (Design 3, Design 4).

We explore the differences between our radios with a focus on the aspects in the design that affect performance. We evaluate each of the circuits in the receiver designs, specifically focusing on the following: bandpass filter, local oscillator, mixer, amplifiers, and low-pass filter.

BANDPASS FILTER (BPF)

Bandpass filters are widely used in radio receivers as they allow the designer to change the frequency agility of the radio receiver. Design 1 utilizes a fixed 3

rd order Bessel LC bandpass filter. By using a series-first topology, a coupling capacitor can be saved. While a design with a fixed bandpass filter is easier to make, maintain, and fit on a small board, it doesn’t offer the flexibility and performance that switchable bandpass filters allow radio enthusiasts.

Designs 2 and 3 both utilize switchable bandpass filters, controlled via two digital output pins on an Arduino Nano v3. With careful planning, the switchable bandpass filters better eliminate spurious signals as discussed above and reduce the overall noise. This increase in performance comes at the price of design complexity. With the introduction of multiple BPFs, the need for a switching circuit (a 4:1 multiplexer is a perfect solution) and software to control the filters are needed. Additional bandpass filters also add more passive components to the board, taking up precious PCB space.

For a designer who has a fixed frequency band with which he would like to communicate, a single bandpass filter is more than adequate. The pure minimalist could even neglect using a bandpass filter. Excluding the BPF exchanges the inclusion of a few spurious signals for a receiver that is light, compact, cheap, and easy to assemble and debug. Design 4 takes on a composite approach, placing pin headers for an optional bandpass filter to be installed post-facto.

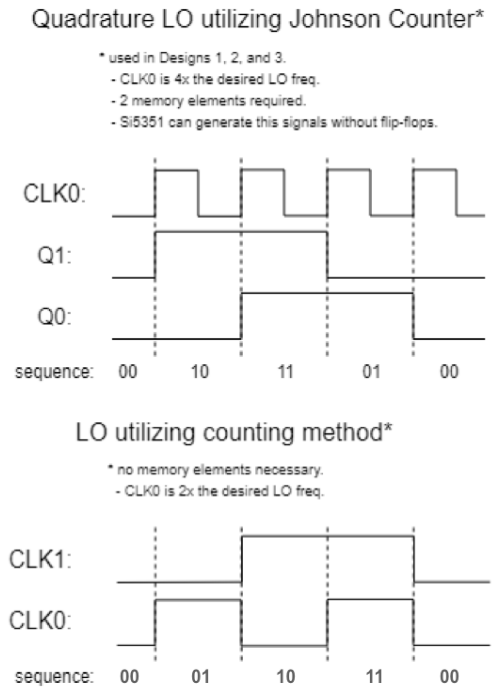
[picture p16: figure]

LOCAL OSCILLATOR

The clock generator and local oscillator (LO)
configuration is homogeneous for the first three designs. A Si5351a clock oscillator is used to generate the LO signal and dual flip-flops connect as a divide-by-four Johnson counter to produce the I and Q local oscillator signals at one quarter the frequency of the driving clock. This approach offers a large bandwidth, as the LO can vary from the lower limit of the Si5351a of (2.5 kHz)/4 to the maximum frequency of (200 MHz)/4.

Following the design of the µSDX transceiver by Guido Ten Dolle, Design 4 capitalizes on the capabilities of the Si5351a to generate the I and Q
signals | without | the | need | of | flip-flops.
Programmable via the I²C protocol, the Si5351a allows you to lock the phase of the two clock outputs, to generate two signals at the same frequency and in quadrature. The Si5351a does, unfortunately, place a limitation on the range of frequencies that can be generated. Utilizing the Arduino Etherkit Si5351 library, written by Jason
Milldrum, | NT7S, | the | minimum | quadrature
frequency that can be generated should theoretically

be 600 MHz/128 = 4.6875 MHz, because the phase register is 7 bits and the minimum PLL frequency is 600 MHz. However, through direct I²C programming, Guido works the minimum quadrature frequency down to 3.2 MHz, fully encompassing the popular 80-meter band (3.5 MHz to 4.0 MHz).iii

If the minimum frequency of the quadrature method is not low enough for the desired application, there is an alternative solution. By utilizing two clocks, a sequential counting sequence (00, 01, 10, 11) can be obtained by setting the low order bit to change at two times the desired local oscillator frequency. The higher bit is then set to be half the frequency of the low bit using a divider built into the Si5351a that keeps the bits synchronized. A timing diagram comparing the counting method to the quadrature signals generated via a Johnson counter is shown in Figure 16. Interestingly, generating quadrature signals directly from the Si5351a increases image rejection. The quadrature method utilized in Design 4 provides 40 dB of image rejection, and Guido gets 45 dB. Experimentation and testing showed that the Johnson counter LO in Design 2 has 30-35 dB of image rejection, while the well-known SoftRock RXTX we tested only has 25-30 dB depending on the part of the passband you are in. Bottom line: use the quadrature method for frequencies above 3.2 MHz and the counting method if frequencies below 3.2 MHz are desired. Both

Figure 16. Square wave visual representation of how the counting sequence differs between the two types of local approaches will result in more software than utilizing a Johnson counter, but they cheaper solution and save board space.

MIXER

An important consideration in the design of SDR receivers is selection of a mixer topology that combines the signal of interest and the local oscillator output. When evaluating mixers, it is imperative that one compare the conversion losses, or the ratio of the RF input power to the IF SSB output power, expressed in positive dB iv
. The lower the conversion losses, the more efficient a mixer is at converting energy from the RF to the IF signal. Noise is also a concern and should be considered when designing a mixer.

While there are numerous types of mixers, we utilized two common designs. Design 3 utilizes a doubly balanced sampling mixer, essentially a switch with a capacitor feeding into a summing amplifier. If the amplifier selected has a high impedance input, the capacitor will hold the input voltage when the switch is open. This allows the duty cycle of the switch to be lowered, which results in a lower conversion loss. Design 3 does not have this advantage as the amplifier configuration utilized has a low impedance input, as we’ll elaborate on in the next section. The mixer in Design 3 is doubly balanced due to the center tapped transformer that negates the RF input signal for half the period.
An extension of the sampling mixer design well known among radio amateurs is the Tayloe detector. Despite its striking similarities with the sampling mixer, Dan Tayloe emphatically states that his detector is not a mixer since it only produces the difference frequency. Perhaps that means Design 3 uses a sampling detector too. All but one of the designs presented in this paper utilized the Tayloe detector due to its compact, simple design and low conversion loss (less than 1 dB). In a comparison of switch-based frequency converters by Michiel Soer, it was concluded that the “a double balanced Tayloe mixer with 25% duty cycle provides the best balance between noise figure and conversion loss”

v
. The low-cost, high-performance Tayloe detector is one of the better options for SDR receiver designs.

AMPLIFIERS

While the first two designs (Designs 1 and 2) share many fundamental similarities: (they both utilize bandpass filters and a Tayloe (I/Q) mixer to convert the radio spectrum to a low IF which is then demodulated via software) the key difference between the two lies in the amplification of the IF signals. Design 1 utilizes instrumentation amplifiers while Design 2 utilizes a basic differential amplifier. The biggest difference between these two amplifiers is the input impedance. The instrumentation amplifiers provide a very high input impedance which makes the amplifier more like a voltage amplifier, while the differential amplifier more closely resembles a transresistance amplifier due to its lowered input impedance. The input impedance is a byproduct of the type of amplifier topology. As seen in Figure 17, the instrumentation amplifier used in Design 1 internally utilizes a non-inverting topology which completely isolates the input signal from the output. On the other hand, the inverting topology of the differential amplifiers allows for current to sneak through the feedback loop. This difference in amplifier topology, and subsequently the input impedance of the amplifier introduces a multitude of intriguing effects that influence other aspects of SDR receiver design.

For one, the difference in input impedance affects the way that the mixer sampling capacitor functions. With the high input impedance of the non-inverting topology, the sampling capacitor follows the RF signal when the switch is closed and holds the voltage level when the switch is open, since there is no path for the capacitor to discharge. However, the inverting amplifier with its lower input impedance doesn’t charge the sampling capacitor as much.
A voltage amplifier with high input impedance also uncouples the amplifier stage from other sections of the design, discretizing the SDR receiver into a system of easily understood blocks. The many interdependencies experienced with a coupled amplifier design (like Design 2) are eliminated, allowing for easier design. Debugging is also easier in a voltage amplifier like Design
1. The tools that we have at our disposal (oscilloscope, multimeter, etc.) measure voltage much easier than current. Since each designer shared the same primary goal of furthering their

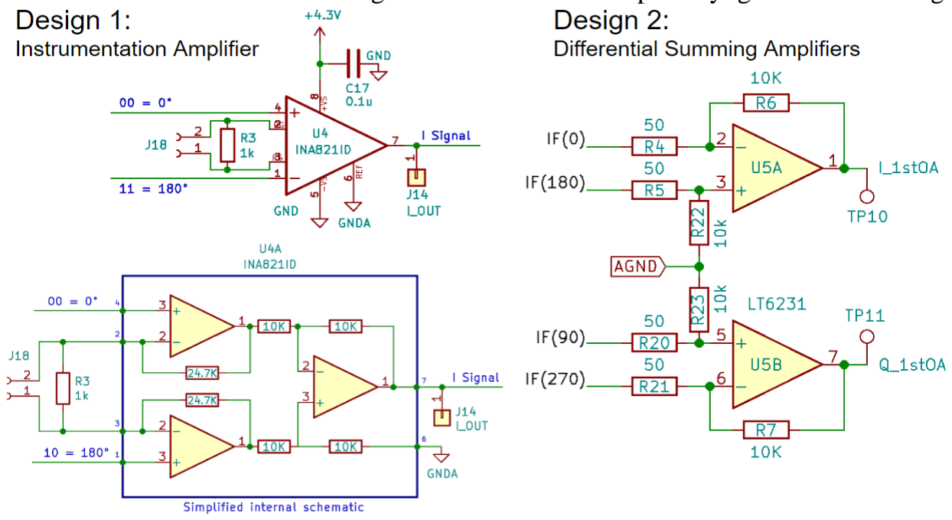
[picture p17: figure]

understanding of electronic engineering concepts, the simplicity and understanding that the instrumentation amplifier provides cannot be understated.

Additionally, instrumentation amplifiers remove the ambiguity of antenna impedance from the amplifier gain equation. Design 1 utilized an INA821ID instrumentation amplifier. Since a single resistor sets the gain of this amplifier, it would be trivial to provide two or more gain settings through a relay or switch. This would allow for further optimization and customization of the radio receiver.

The primary advantage of the differential summing op amp is that it can possibly provide a lower noise figure especially at low gain settings, but for HF the atmospheric noise is large enough that if you pick low noise parts, your design should be fine. The voltage noise and noise figure of instrumentation amps increase with decreasing gainvi. Because of this, instrumentation amps are less attractive for low gain situations below about 20 dB, though the differential summing amplifiers have similar problems. The price and availability can make differential summing op amps a more appealing option for a Ham radio amateur on a low budget. The single-circuit

Figure 17 - Comparison between amplifiers used in Designs 1 and 2.

INA821IDs utilized in Design 1 were 6% more expensive than the dual-circuit LT6231s utilized in Design 2.

Despite | their | dissimilarities, | both | the
differential summing amplifier (utilized in Design 2) and the instrumentation amplifier (utilized in Design 1) take the difference between the IF signals (v0° and v180°, v90° and v270°) In the case where a specific linear combination of the signals is desired (i.e. v0° – v180°) and the other combinations are undesirable, then a differential amplifier or
instrumentation | amplifier | is | optimal.
Differential amps magnify the difference signal and reject the common mode signals through clever balancing of the circuit. But in our case, either v0° or v180° or any other linear combination of these signals can be used. Dan Tayloe’s quadrature detector design exploits this fact by eliminating all the input and bias resistors and maintaining just the feedback resistors of the amplifier. This results in the non-inverting path gain not equaling the inverting path gain, and the amplifier does not sum differentially. A side effect of straying from the classic differential amplifier is a larger common mode gain, however in this case the common mode gain is one, just perfect, so the amplifier in Design 4 doesn’t need to be DC biased like the amplifiers in designs 1 and 2. This produces a more simplistic design with less parts, reduced power loss and a decreased input noise level.

Design 4 follows Tayloe’s approach for

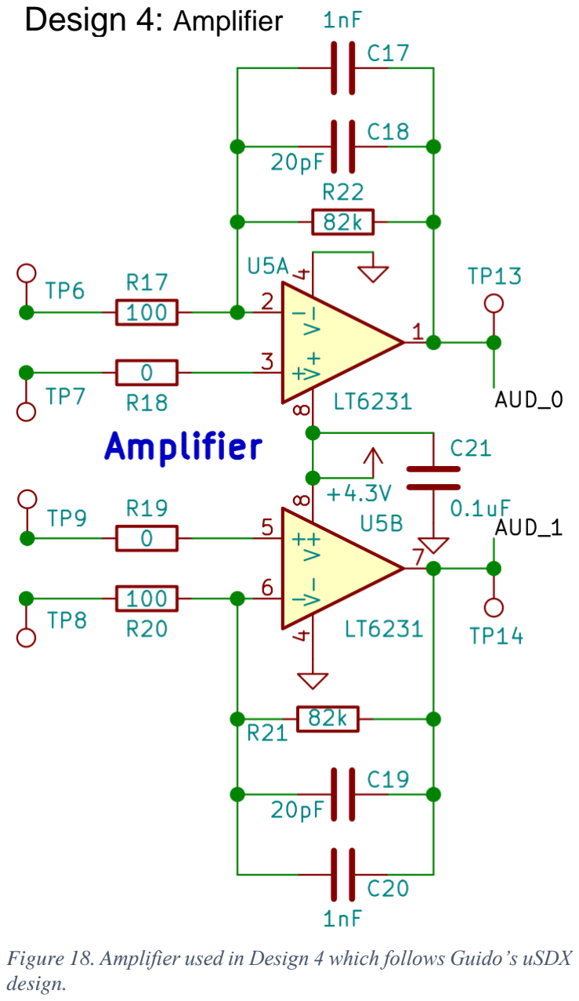
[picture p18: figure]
design.; Design 4: Amplifier

amplification yet maintains the input resistors before both inverting outputs so that the gain of the amplifiers is not solely dependent on antenna/system resistance. Resistors before the non-inverting capacitors (R18 and R19) are included in some designs to make the system more symmetrical. However, they have no effect on the operation of the amplifier, other than adding a little noise, so the present plan is to replace them with wire. The two capacitors on each feedback path allow for slightly different cutoff frequencies and eliminate the need of a separate low-pass filter. Two filters are necessary in Design 4, with the bandwidth set at about 6 kHz, as all the digital signal processing (DSP) can optionally be done on the board itself and without the horsepower of a PC using Guido’s great code. This allows the sampling to be conducted at a slower pace so that the processor has more time to filter the signals, but no spectral display is possible using only the MCU.

Figure 18. Amplifier used in Design 4 which follows Guido’s uSDX

LOW PASS FILTER
Separate low-pass filters are utilized in the first two designs. Design 2 uses the low-pass filter to distribute the overall gain of the receiver across two different amplifier stages. The differential summing amplifiers have a theoretical gain of 46 dB (200 V/V) and the low-pass filters contribute another 20 dB (10 V/V) of gain. By placing more gain in the preamplifier stage before the signals get too big, the amplifiers in the low-pass filter don’t have to be as robust. Design 2 could have avoided the use of a low-pass filter altogether by simply placing a capacitor in parallel with the feedback resistors of the summing amplifiers, however, the 2nd order Butterworth filter boasts an extra pole of attenuation over Designs 3 and 4. Design 1 must use a secondary low-pass filter since the negative feedback loop occurs internally inside the INA821’s. Some instrumentation amplifiers can be purchased with access to the feedback loop; however, these amplifiers are far too expensive for a low-budget radio project. Design 1 utilizes an LPF with no gain since the gain is already controlled by instrumentation amps. Additionally, the noise figure for the INA821s gets better with increasing gain, thus, minimizing the gain on the low pass filter helps improve overall system noise.

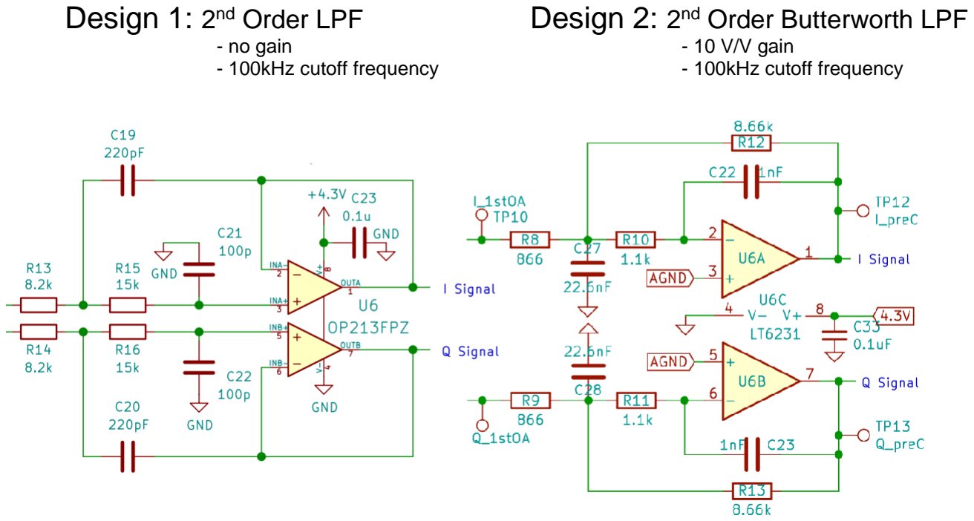
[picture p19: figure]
Design 1: 2; nd Order LPF; - no gain - 100kHz cutoff frequency; Design 2: 2; nd Order Butterworth LPF; - 10 V/V gain - 100kHz cutoff frequency

OTHER DESIGN NOTES

Ground loop noise is minimized in Design 2 using a transformer to isolate the radio antenna from the receiver. Experimentation and testing found that the noise level was reduced by nearly 20dB (from –90dB down to –110dB) thanks to the inclusion of the transformer. The transformer is directly responsible for removing ground loops.
Grounding problems can arise when there are multiple different paths to ground. A ground loop is formed when there are two ground connections between a component and the ground plane. This loop acts as a single-turn inductor and can infuse substantial noise into the audio signal, corrupting the signal. Since SDR radios utilize extremely sensitive audio cards, it is imperative to take

Figure 19 - Comparison of 2nd order filters used in Designs 1 and 2.

precautions to avoid the devastating effects of ground loops (see the design guide for more details)
vii

Maintaining a clean power source is also important towards minimizing noise. When powered via a USB, the SDR can experience a lot of noise due to the rapid switching that happens in computers. The solution utilized in all the designs is a common emitter (CE) amplifier that regulates and smooths the output voltage at the emitter. In the first three designs, an RC low pass filter with a cutoff frequency of 16 Hz is used. Design 4 utilizes an LC low pass filter with a cutoff frequency of 90 Hz. Even though this is a second order filter, it did not provide appreciable improvement in the noise levels, whereas the RC network in Design 3 did. It is not recommended to copy this circuit as it was not carefully designed. The only downside to the CE amplifier is it comes with an approximate 0.7V drop across the transistor. Depending on the IC’s selected in the design, this 0.7V loss could be significant. Including a bypass jumper allows flexibility to test operation on 4.3V or 5V to determine which is preferred.

| MDS (µV) | Image Rejection(dB) | Power Consumption (Watts) | Cost ($) | Size (cm x cm)
Design 1 | 0.5 | 30 | — | $30 | 10.0 x 10.0
Design 2 | 0.5 | 30 | — | $25 | 10.0 x 10.0
Design 3 | 0.1 | 15 | 5V · 0.027A | $25 | 5 x 10
Design 4 | 0.5 | 33-40 | 5V · 0.035A | $25 | 5 x 10
SoftRock RXTX | 0.2 | 25-30 | 12V · 0.028A | $75 | 6.35 x 12.7

Table 1. Quantitative Design Comparison performance summary.

DESIGN GUIDE

After spending many hours researching quadrature sampling down-conversion receivers, we decided that creating a condensed design guide to creating a QSD SDR receiver would be beneficial to the amateur radio community and draw interest from a less experienced audience that may have otherwise become lost in the process. The QSD receiver is best for simplicity, power consumption, cost and size. However, if better image rejection and the ability to tune many receivers with the same SDR are desired however, a digital down conversion (DDC) receiver is more appropriate.

The first thing to consider when designing this type of SDR receiver is, “What is your goal for building one?” Is your aim to experiment with electronics? Have a working radio for cheap? Take the radio backpacking? Is there a specific range of frequencies you are hoping to listen to? Do you want it to be as small and lightweight as possible? Or are you shooting for building the highest quality radio possible? These are all questions you should ask yourself beforehand, as the answers can greatly affect your design choices.

In this design guide, we try to break down the design process into a step by step manual. At each step, we provide tables with several design choice options and explanations of when using each option may be appropriate based on your goal with your radio. We also provide relevant equations, links to online design tools, and general board construction and testing tips we found helpful when designing our own radios. We specifically address the documentation and design preparation, hardware design, circuit simulation, board layout and build, and software with regards to software-defined radio design and construction.

DOCUMENTATION AND DESIGN PREPARATION

The documentation and design preparation are foundational for any project. Keeping careful documentation is important because it can not only help remind yourself of the design and test procedures conducted, but it can also be useful to others who are looking at your project for reference. Documentation can take many forms, from paper and pencil to a GitHub repository. Keeping careful record of corrections needed, mistakes made, concepts learned and more can be of great benefit in the long run. We found Kicad’sviii schematic capture tool, EEschema, was a real help in documentation and design.

Design Planning: When designing electronics,
it is helpful to create a block diagram as shown in Figure 20. Each block can then be designed separately. In addition to designing the project in segments, try to anticipate problems and incorporate possible solutions in your design. In concordance with anticipating issues, make trouble shooting the issues easier by adding
many test points and pins for bypassing entire sections. Being able to identify the problem can

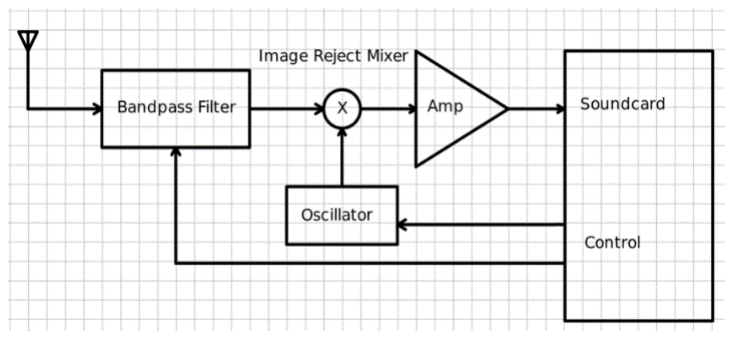
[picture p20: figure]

sometimes be even more challenging than resolving it.

Circuit Simulation: It is crucial to confirm that the design will work using a simulation software before building a prototype. For our receivers, LTspice was used to simulate each component. This will not ensure that the final design will work. However, this will prevent many mistakes that could have been made. It is recommended to start simulating with “ideal components” as this will speed up runtime and makes simulating easier. Once a design is complete and you are ready to pick parts then you can simulate real-world components to find parts that will work for your application. The circuit simulation is discussed in depth in a later section.

Component Selection: There are multiple options when selecting components to use on your circuit board. One of the more important things to keep in mind is to select components you are comfortable soldering. Many individual components (resistors, capacitors, ICs) come in different packages. A summary of the two primary types of packages described in Table 2.

TYPE | DESCRIPTION
SMD/SMT | Surface Mount Device/Technology is smaller and is generally soldered onto the surface of the board using solder paste. An oven reflows (melts) the paste which then cools and hardens onto the solder pad. If you do not have access to an industrial reflow oven, a $20 toaster oven can work just fine. These components tend to behave more ideally than their THT counterparts because they have no leads. Leads have unwanted parasitic inductance and capacitance. Another advantage is this package type can be cheaper than THT. Furthermore, if you

Figure 20. Example Block Diagram

| have the equipment and steady hands, it is easier and faster to assemble boards using this package type. However, we recommend not using anything smaller than the 0805 package size, especially if you are inexperienced placing components by hand with tweezers.
THT/THD | Through-Hole Technology/Device components, an older technology, are generally larger and the pins of the device stick through the circuit board which can then be secured using a standard soldering iron. This is by far the simpler method for those with little to no experience. It is also cheaper to begin with as you do not need to purchase any additional equipment to attach these components. If you anticipate needing to switch out component values, designing plug-in sockets for THT components can serve as a potential solution.

Table 2. Comparison of component package types.

It is also important to choose components that are not obsolete and are easier to find. The simplest way to do this is to go to your favorite electronics part’s website (Mouser or DigiKey work great) and sort the parts you are looking for by availability. Manufacturers will stock the parts most used in industry. When in doubt, check the datasheets for the components to confirm the specs. It’s also important to choose these parts with high availability as the lead-time to order parts not in stock can take at least 6-8 weeks.

HARDWARE DESIGN

General Good Hardware Design Practices: Use a bypass capacitor at every IC and transistor. A bypass capacitor is a capacitor from the DC power pin to ground. It needs to be as close as possible to the IC or transistor it is bypassing. Often 0.1uF ceramic capacitors are used. The purpose is to ensure that the DC power supplies look like short circuits for AC currents. If they are not used the parasitic impedance of conductors connecting them to the actual DC source cause problems the designers were not anticipating, because they designed as if DC sources were true AC shorts.

Bandpass Filter Selection: As discussed previously in the design comparisons, there are several options when considering using bandpass filters. The type of bandpass filter selected is dependent on the type of radio you desire to build. The first question to consider when selecting a bandpass filter is the preferred filter complexity. Table 3 summarizes reasons for selecting to omit the use of a bandpass filter, use a single fixed filter, frequency specific filter, or opt for a switchable bandpass filter.

FILTER COMPLEXITY | PURPOSE
No Bandpass Filter | Desired if the user prioritizes simplicity over a clearer signal, or perhaps wants to add an external filter later.
Single Fixed Bandpass Filter | Ideal for receivers where the user knows in advance a specific range of frequencies they wish to listen to.
Switchable Bandpass Filter | Preferable for users who wish to eliminate as many spurious signals as possible while maintaining the ability to listen to a large range of frequencies. One octave (the lower cutoff frequency is half the upper) is a good design choice when using multiple filters.

Frequency
Specific Filter

If certain signals are known to be problematic, filtering out only the problematic signals such as a local AM station may be adequate.

Table 3. Different bandpass filter complexity selections and suggested application for selection each type.

After determining the complexity of the filter, the next step is to decide the type of filter. LC filters are the best choice for most HF radio applications, so a list of different types of LC filter configurations are listed in Table 4 along with their advantages and disadvantages. It should assist in determining which type of filter is appropriate for your application.

The final few things to consider when designing the bandpass filters are selecting the frequency range, input and output impedance, the order, and choosing a series-first or shunt-first configuration. Once these characteristics are determined, the next step is to calculate the inductor and capacitor values. These values can be easily calculated through an online calculator such as that at RF Tools (https://rf-tools.com/lc-filter/).

The center frequency and bandwidth are selected based on your interest. Note that the wider the bandwidth, the lower the quality. Likewise, a narrow bandwidth increases quality. It is also important to match impedances. When the input impedance does not match the antenna and the output impedance does not match the load, the filter will not have the desired response. When matching impedances, the input impedance does not necessarily have to equal the output impedance. Rather, the filter tools give us the freedom to choose different input and output impedances. This is advantageous when designing the filter because we can have the input impedance equal to that of the antenna, then choose the output impedance to match that of the remaining circuitry, specifically the impedance of the amplifiers. For example, if we were using an instrumentation amplifier which has a theoretical input impedance of infinity, it would be appropriate for us to choose an output impedance of 10MΩ and input impedance of 50Ω for our bandpass filter. The order of the filter determines the effectiveness of the filter. The higher the order, the steeper the roll-off, and therefore the more effective the filter. However, as the order is increased, the magnitude by which the effectiveness is increased decreases, because nominal filter component values are never exact. Typically, we find a sweet spot around the 3rd order. Lastly, one can choose between series-first (T) or shunt-first (Pi) configurations. If you are using 50 Ω and 10 MΩ as in the previous example, shunt is preferable over series because the series filter will require component values that are very hard to make or procure.

FILTER TYPE | ADVANTAGE | DISADVANTAGE
Butterworth | Very flat response within passband with essentially no ripple. Low level of overshoot. Linear. Tolerant of component variation. | Reaches ultimate roll-off rate more slowly thus the performance around the cut-off frequency is poor.
Chebyshev | Provides faster transition from passband to stop-band. Steep roll-off provides significant attenuation of unwanted out of band spurious signals and limiting harmonics. | This fast transition comes at the cost of in-band ripple. Less tolerant of component variation.

Elliptic | Produces the fastest transition from passband to stop band of any type of filter. | Presence of gain ripple in both passband and stop-band.
Bessel | Very flat group or linear phase delay. Therefore, it is ideal for applications where the wave shape of signals within the passband must be preserved. No overshoot. Linear. | Slower transition from passband to stopband than other filters in this table, of the same order (slow cut-off).

Table 4. Comparison between the different types of bandpass filter topologies and their advantages and disadvantages ix

With the design of the bandpass filters complete, the last task is to gather components. You should strive to get inductor and capacitor values as close to the calculated ones as possible or simulate the filter in LTspice or similar circuit simulator to visualize the effect of variations in component values. Some components, such as bypass capacitors, are not very sensitive to the value, but filter components are. For the capacitors, surface mount capacitors work slightly better, because of their low parasitics, but really either works perfectly fine for most HF filters. The inductors can either be purchased pre-wound as a through hole or surface mount part (caution: make sure that it is rated for the appropriate frequencies), or you can make them yourself using powdered iron toroids and wire. Some inductors are lossy. These are less desirable, and if used, you need to simulate the losses, and make sure you are okay with the effects. There are several online winding calculators, two that we’ve found to work well are:

- http://www.66pacific.com/calculators/toroid-coil-winding-calculator.aspx
- https://toroids.info

Hand-wound transformers provide a high-quality solution by minimizing losses. However, they are not the cheapest option, and take time, effort, and testing to ensure proper operation. Because winding inductors by hand tends to be time consuming and tedious, generally we try to select bandpass filters with central frequencies and bandwidths that enable us to limit the number of inductors needed in a circuit and keep their values low.

An important note when doing the board layout for the bandpass filters is to recognize the influence the components may have on each other. Generally, iron powder or ferrite toroid cores will keep their magnetic field relatively close, allowing the designer to place the components close to each other without any issues. However, if the designer chooses to use an air core, then mutual inductance may become an issue. It’s also good practice to add a surplus of test points, with at least one before the filter and one after for each band. For further ease of testing, we recommend connecting the bandpass filter to the rest of the circuit using jumpers. This way, the user can easily bypass the bandpass filters for troubleshooting purposes.

Ground-Loop Avoidance: Simple solutions can often be used to solve the ground loop problem. Design 1 places a jumper wire from a component to the ground plane that helps break ground loops. While this is simpler and cheaper than winding a transformer, it’s not as universal. Jumper wires can be finicky and require readjusting when the receiver is moved to a new QTH. We recommend using a 1:1 transformer between ground and the antenna. This solution is reliable and rugged in mitigating ground loops. If hand-winding a transformer using wire and a toroid core, the following equation can be used to calculate the inductance of the transformer given an impedance of 50 Ω:

wLm ≫ Rs | ⇒ | 2πfLm = 50Ω(20) | ⇒ | Lm =

50Ω(20)
2πf
With the inductance calculated, you can now use an online calculator like the ones listed previously to determine the number of windings. Another method used to help avoid ground loops is to have a single ground reference plane on the circuit board and use flood fill with ground on both sides of the printed circuit board. Some radios may not need any ground loop mitigation. For example, when using a battery connected very close to the PCB, with a self contained SDR like Guido’s or Design 4. In general, if there is more than one connection to ground, then watch out for ground loops.

Voltage Smoothing: If you use one of these circuits to remove noise coming from the computer’s USB port, use the one from Design 3, rather than Design 4. The latest one was not carefully designed and did not improve the noise, while the voltage smoother from Design 3 did in a significant way.

Local Oscillator: There are various options for local oscillators, but all four designs from this paper used the same chip, the Si5351A. As mentioned previously, three different configurations were used and are summarized in Table 5.

TYPE | PARTS REQUIRED | COUNTING ORDER | FREQUENCY RANGE
Johnson Counter Circuit | 2 (Dual D Flip-Flops, Si5351a) | 00, 01, 11, 10 | 2.5/4 kHz to 200/4 MHz
Counting Method | 1 (Si5351a) | 00, 01, 10, 11 | < 3.2 MHz
Quadrature Method | 1 (Si5351a) | 00, 01, 10, 11 | > 3.2 MHz

Table 5. A comparison of different local oscillator configurations and important characteristics.

When constructing the local oscillator of the SDR receiver, be aware of the voltages of different devices. For instance, the Si5351a is inherently a 3.3V device whereas an Arduino Nano is a 5V device. We need to be careful when connecting different voltage devices. We can connect devices with different logic levels by the use of a pull-up resistor to the lower voltage device. In the case of this example, we would have pull-up resistors to 3.3V as recommended in the Si5351a datasheet. However, in our experimentation, we found this method inconsistent. A safer approach would be to implement the use of a level shifter such as that used by Etherkit. The schematic by Etherkit is shown in Figure 21x where the pull up resistor and MOSFETS that are part of the level shifter are connected to the SCL and SDA pins of the Si5351a clock generator. More information about level shifters can be found at:

- https://etherkit.github.io/si5351abb_landing_page
- https://www.nxp.com/docs/en/application-note/AN10441.pdf
- https://www.digikey.com/product-detail/en/diodes-incorporated/2N7002DW-7-F/2N7002DW-FDICT-ND/750003 (https://www.digikey.com/product-detail/en/diodes-incorporated/2N7002DW-7-F/2N7002DW-FDICT-ND/750003)

Mixer Selection: Based on the discussion on mixers described in an earlier section, we recommend you use a Tayloe Mixer. An SN74CBT3253 or a similar IC can be used as the 4:1 multiplexer. The schematic for the Tayloe Mixer will typically take the form shown in Figure 22xi .
The sampling capacitors, as part of the Tayloe Mixer configuration, can be selected based on the following equation:
C =

1

n×π×fReceiverBandwidtℎ×R

R is the antenna impedance plus any other impedances in series before the sampling capacitor, n is the number of capacitors being charged, and fReceiverBandwidtℎ is selected by the designer. The sampling capacitors essentially become a simple RC low-pass filter when analyzed with the impedance, R.

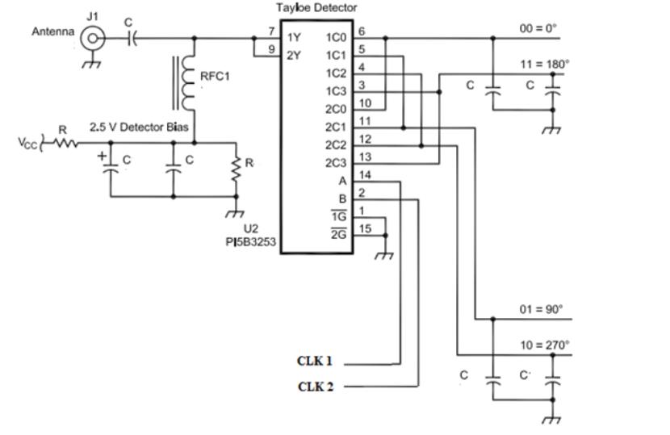
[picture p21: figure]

Figure 22 - Tayloe Mixer Schematic with CLK 1 and CLK 2 as select line inputs to 4:1 multiplexer and sampling capacitors, C, on the 00, 11, 01, and 10 outputs of the multiplexer. The RF signal comes directly from the antenna to 1Y and 2Y. xi

Figure 21 - Etherkit Schematic of the Si5351a with level shifter.

Amplifiers and Low Pass Filter Selection: In order to design the amplifiers and LPFs properly a few things must be considered. Op-Amps can be expensive, so the model chosen has to balance cost and efficiency. The best way to do that is to compare the datasheets of the amplifiers to the specifications required. From the designs shown in this paper, a common IC that is used in Design 2 is the LT6321, chosen for its low noise performance and built-in model for LTspice simulations. The INA821 instrumentation amps used in Design 1 have the benefit of low noise, effectively infinite impedance on their inputs, and gain set by a single resistor, but are quite costly. The instrumentation amplifiers appear to be the simplest to analyze since they act purely as a voltage amplifier whereas the differential amplifiers act as trans-resistance amplifiers. The amount of gain on the amplifiers implemented post-mixer should strive to keep the signal to noise ratio within reason for the given application while also taking into account the sensitivity of the ADC of the soundcard to minimum voltages. Choosing an amplifier that has a pre-made or built-in spice model can be very useful for quality simulation. If there are no pre-made models for one you’ve selected, you can use the universal op amp model, and fill in the appropriate specifications for the one selected. The NE5532 and SA5532 are op amps with not quite the noise performance of the LT6231, but a much lower price. They can be had in the same package as the LT6321, so could be substituted for a less expensive receiver, especially for the lower bands using the same bands with the same PCB.

For | low-pass | filters, | we | utilized | the | online | Filter | Design | Tool | from | Texas
Instruments: https://webench.ti.com/filter-design-tool/filter-type. This saves time as you can get a complete filter design in minutes if you know the parameters needed. More in-depth discussion on the amplifiers and low-pass filters are presented earlier in this paper in the Design Comparison section.

CIRCUIT SIMULATION

Simulating a circuit before building the hardware, as mentioned briefly before, can save the designer many hours of troubleshooting. Often, simulation illuminates potential issues that weren’t easily visible before. When an issue is identified in simulation, it is much easier to change the simulation component than it is to solder and de-solder a component from a physical board. In this section, we show several circuit examples with advice on how to simulate them properly. Images are included here, but the LTspice .asc files are available for download at http://fweb.wallawalla.edu/~frohro/ClassHandouts/?dir=Electronics/LTspice_simulations_of_QSD_SDR_Receivers. (https://fweb.wallawalla.edu/~frohro/ClassHandouts/)

LTspice Introduction: We primarily used LTspice for our circuit simulations. LTspice is a “high performance SPICE simulation software, schematic capture and waveform viewer with enhancements and models for easing the simulation of analog circuits.” It can be downloaded for
free | at | https://www.analog.com/en/design-center/design-tools-and-calculators/ltspice-
simulator.html (https://www.analog.com/en/design-center/design-tools-and-calculators/ltspice-simulator.html) and runs on Linux, OSX and Windows. LTspice also has many readily available help resources including help forums and instructional YouTube videos.

Circuit Simulation Examples: The portions of the SDR receiver circuit that are essential to simulate beforehand are shown with some examples here. Figures are paired with descriptions of what each circuit simulates and how to use appropriate run commands for each.

The bandpass filter hardware design can easily be simulated in LTspice using an AC analysis, though the design tools also give simulated results. Figure 24 demonstrates the topology of a Bessel 3rd order bandpass filter generated through the RF tools website. When simulating the bandpass filter, it is important to include the input and output impedances. Here, the output impedance was assumed to be a 50Ω load as shown by R12. The input 50Ω impedance was included intrinsically in the voltage source V6. To implement an ac sweep, first select a small signal amplitude. For this example, the amplitude was set as 0.5mV. We selected a decade sweep

with 100 points per decade spanning a frequency range from 1kHz to 100MHz. The results of running this simulation are shown in Figure 23.

Simulating the mixer in LTspice can potentially save hours of time in the long run. For this example, we will show you the simulation schematic for a Tayloe Mixer. Since LTspice is an analog circuit simulation tool, the 4:1 multiplexer used in the circuit must be illustrated by voltage-controlled switches. Recall that the Tayloe Mixer uses a local oscillator to drive the select pins of the FST5351 or similar multiplexer to “mix” the local oscillator frequency with the RF from the antenna. We use voltage-controlled switches and specific signals for the voltage sources to simulate this “mixing” phenomenon. There are two primary ways of specifying the signals in the voltage sources for the voltage-controlled switches.

The first way is by using the PULSE voltage source style. Figure 26 shows the LTspice edit menu for inputting the settings for the pulse waveform. The pulse waveform is used to generate a square wave at 4 times the switching period to turn the voltage-controlled switch on when the wave is above a specified voltage. We use 4 separate switches controlled by 4 separate pulse waveforms.

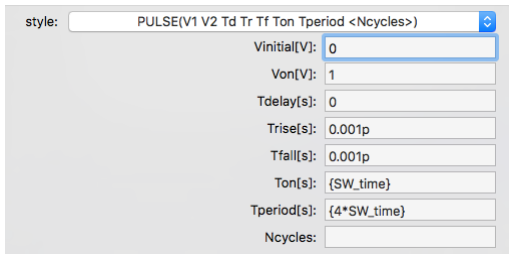
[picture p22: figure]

Figure 26. Settings for the PULSE wave 0-degree voltage control

Figure 23. Output of the Tayloe Mixer Simulation with no load attached.

Figure24. LTspice Bandpass Filter Simulation | Figure 23. Bandpass Filter Simulation Results

The only difference between each pulse wave is the delay time (Tdelay[s]). This delay is essential in generating 4 signals that are out each 90 degrees out of phase with each other.

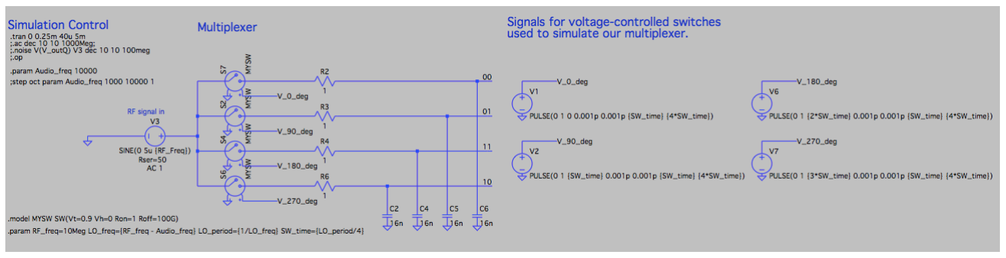
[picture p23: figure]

The second way is by using four voltage sources as sine waves that are phase shifted 90 degrees from each other. We phase shift them by editing the sine function, as shown in Figure 29, such that Φ is the degree (0, 90, 180, or 270), the frequency is 10kHz less than the RF signal phase, and the amplitude is at least 50V. Another important thing to note is that in order for this circuit to work as a multiplexer, we must change the switch model. The model must be adjusted such that Vt is the appropriate value, as shown in Figure 28. The rest of the circuit topology is the same as the previous illustration.

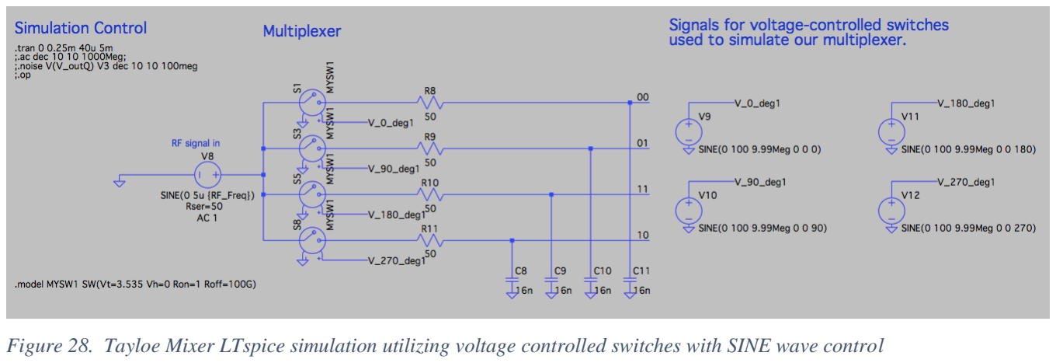
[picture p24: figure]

It is important to note that in order to have a simulation output that looks like Figure 25, we must include the sampling capacitors. The sampling capacitors in this example are C2, C4, C5, and C6. We must also test this mixer without the amplifiers attached. When the amplifiers are attached to the outputs of the mixer, we see a loaded effect as a result of the characteristics of the op-amps, which may not be the result expected. This emphasizes the importance

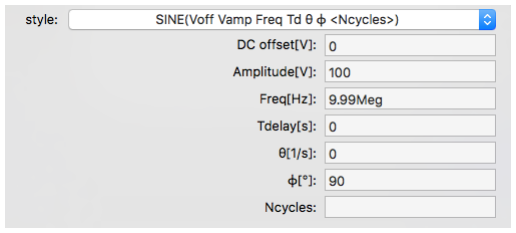
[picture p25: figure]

of | testing | the | receiver | in Figure 29. Settings for 90-degree SINE wave voltage output.

Figure 28. Tayloe Mixer LTspice simulation utilizing voltage controlled switches with SINE wave control

Figure 27. Tayloe mixer LTspice simulation utilizing voltage controlled switches with a PULSE wave control.

compartmentalized sections rather than as a whole. In this way, we can verify each component individually making troubleshooting much easier and faster.

The first method of simulating the mixer is more intuitive and tends to operate more cleanly than the second. The second method offers an easier way of changing the local oscillator frequency. However, with some variables like the local oscillator frequency, period, and switch time coded as .param variables, it becomes just as easy to change the local oscillator values with the first method.

The last section of the circuit that is beneficial to simulate beforehand are the amplifiers and low pass filters with the final I and Q signals that will be entering the audio jack. It’s important to remember that the voltage output from the Tayloe Mixer will not be the same as discussed previously due to the characteristics of the filters and amplifier chosen for the design. There are multiple amplifier topologies that can work for the radio. As mentioned in the design comparison section of this paper, the amplifiers have different characteristics that can be advantageous or disadvantageous in depending on the application. Figures 30 and 31 illustrate two different amplifier circuits and how they can be simulated in LTspice as a starting point for your design. These represent only the I signal. A duplicate of this circuit can be used for the Q signal.

BOARD LAYOUT AND BUILD

The layout of a PCB board can potentially have extreme effects on the performance of the circuit. A checklist of good design practices to keep in mind when designing the board follows:

- Include a prototype area
- Use sockets for components, such as capacitors or resistors, that will likely need adjustment.
- Include add-in areas with jumpers that will allow you to try multiple options on a single board
- Add test points everywhere! This makes testing and troubleshooting a lot easier.
- Strive to make the I and Q signal paths as similar as possible.
- Match component values and paths as closely as possible, as this can impact image rejection.
- Think about the types of connectors you will use on your board: audio jack, SMA, Arduino connector, etc.
Figure 30. Instrumentation amplifier LTspice simulation | Figure 31. Softrock amplifier LTspice simulation topology
topology

- Contemplate the mechanical aspect of the design: how will it fit in a case? Is the display readable? Are the controls or test points difficult to reach?
- Anticipate which traces will be carrying large amounts of current and adjust for this with the trace sizes. There are multiple online tools to calculate trace impedance (and therefore size) for different current values, but we found the KiCad trace impedance calculator to be convenient.
- KiCad provides a bug check in the schematic capture and the board layout tools. Use them! The PCBnew bug check will look for unconnected traces and other violations. Ask a qualified peer to review your schematic especially, and your PCB. Utilize the board manufacturer’s bug checker and their design rules.
- Label the PCB using the silkscreen with important information such as what it is and where the relevant documentation is located.
- Use the 3D viewer on PCBnew to ensure silk screen text is readable and placed correctly.
- Use a flood fill ground plane on both the front and back of the board to avoid ground loops, and to help bypass capacitors do their job.
- Try to keep the analog and digital components separate, because digital components cause analog noise.
- Refrain from having the input and output signals close to each other on the board, as it can lead to oscillation.

Board Bring-Up Plan: Before ordering a printed circuit board, or assembling the electronics, it is helpful to create a board bring-up plan. This is a guide to how one plans to assemble and test the different parts of the radio. By going through each sub-circuit or block as described early, one can troubleshoot sub-circuits and ensure that they work properly before moving on. Before applying power, check each sub-circuit and verify that there are no shorts between power and ground. It is not uncommon for parts to be damaged by electrostatic discharge, or accidents. This is one of several reasons to purchase extra components, especially the smaller package components as one lost or damaged component can set you back a week waiting for new parts.

As part of the board bring-up plan, include debugging strategies. Some debugging tips to keep in mind are:

- Verify jumpers are in the correct places.
- Carefully inspect the board with a magnifier for soldering problems.
- Use an ohmmeter to verify connections
- Check for oscillator signals, as we found sometimes you think they are there, but something happened in your last tests.
- Look for saturated op amps. Saturated op amps have their output voltages close to the power supply rails. They are not amplifying your signal if they are saturated.
- If more noise appears to be present than you like, try checking for ground loops.
- The ground loop may be caused by the computer or soundcard attached to your board.
- Experiment with running the receiver on batteries instead of through a laptop USB port

- Try disconnecting your laptop from ground by running it on batteries instead of the charger connected to the wall.
- Play around with the ground loop jumpers you included to prevent ground loops in anticipated problematic areas (if applicable).
- Add transformers to isolate the antenna input and the audio output.

A good example of a board bring-up plan can be found here:

- https://github.com/froeca/Software-Defined-Radio/blob/master/Milestone_Submissions/Board%20Construction%20and%20Testing%20Plan.pdf (https://github.com/froeca/Software-Defined-Radio/blob/master/Milestone_Submissions/Board%20Construction%20and%20Testing%20Plan.pdf)

Ensure that the designer has an adequate test bench to assemble and troubleshoot the device. Ideally one should work in a well-lit space at a large desk with an anti-static mat. For the SDR radio we required a multimeter, signal generator, and an oscilloscope for a basic test bench. For an all-in-one solution, many students used a Digilent Analog Discovery 2, a device that plugs into a USB port and can perform the testing requirements for a project like this. The only drawback to this handy piece of equipment, is the limited frequency coverage it affords. This can be somewhat addressed by using harmonics of the signal generator for frequencies above 10 MHz. In addition, be sure to have a good soldering set up. A good kit may include the following.

- Soldering Iron (Wedge tip if possible)
- Solder
- Solder-Wick
- Flux
- Helping Hands
- Magnifying glasses
- Small Fume-Extractor Fan
- Wire Strippers
Remember, always turn off the soldering iron after use to prevent oxidizing the tip. For more soldering tips check here https://www.jameco.com/Jameco/workshop/techtip/soldering-tips.html

SOFTWARE

The software we used was Quisk, a Python program running on the PC, and Arduino code running on the SDR board. The details of installing and setting up the software will not be discussed directly in the paper. However, the following resources cover the software set up and bugs more in detail:

- http://james.ahlstrom.name/quisk/docs.html
- https://groups.io/g/n2adr-sdr/topics
- https://github.com/frohro/IQ_SDR/tree/master/Quisk/Arduino
- https://github.com/KonradMcClure/SDR_Receiver
- https://github.com/greenjacketgirl/SDR_Receiver/wiki/9.-Software
- https://github.com/threeme3/QCX-SSB

A great idea when testing the software is to write simple test programs. For instance, try writing an Arduino program that directly controls the Si5351a rather than one that communicates with Quisk to do so. An example of
a simple test program is found
in Figure 32.

When selecting the soundcard, be aware of the effect it will have on your radio. A sound card with a poor signal to noise ratio can degrade the quality of
your receiver. | Fortunately,
nowadays | there | are
inexpensive USB sounds cards with 24-bit ADCs and at least 90 dB of signal to noise ratio. Another characteristic to check on the sound cards is whether it is dual channel. It must have both a right and a left channel for there to be any image
rejection.

CONCLUSIONS

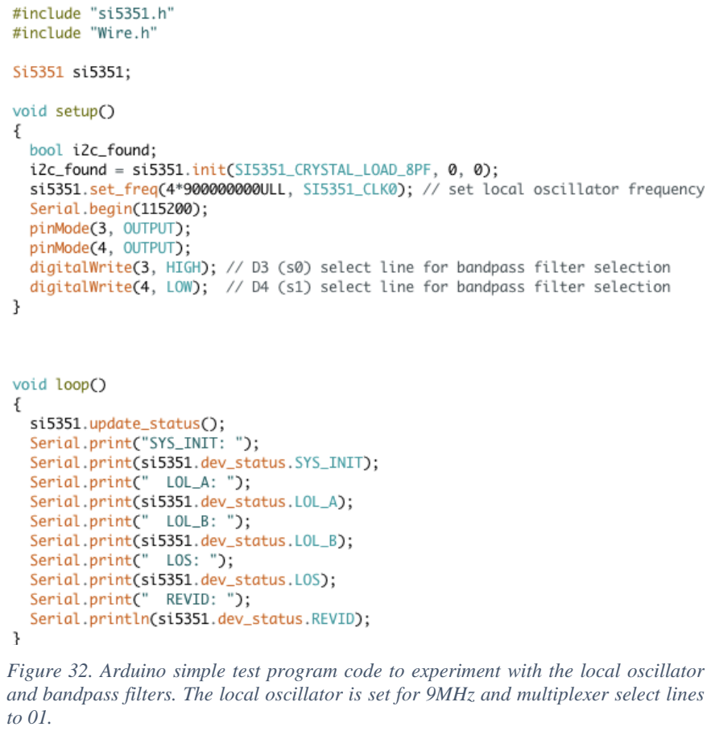
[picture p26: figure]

In this paper, we have discussed the theory behind quadrature signals, drew comparisons between four different self-assembled software-defined radio receivers, and addressed design tips for those interested in building their own SDR receiver. The interest Guido Ten Dolle’s µSDX drew from the community illustrates the relevance of studying and presenting the knowledge we have on similar types of SDR receivers.

We broke down the theory of quadrature signals and mixers into an analogy of plane propeller rotations with visuals to illustrate the concepts. We hope this explanation will help extend understanding about this topic to a larger audience.

Through our design comparison analysis, we discovered that depending on the desired application of your receiver, different types of local oscillators may be selected. In addition, we noted the Tayloe Detector is the best selection for a mixer due to its low conversion loss and simplicity in design. The amplifiers can be difficult to analyze, even in a simulation program, due to some configurations acting as current or transresistance amplifiers rather than solely a voltage amplifier. The instrumentation amplifier presented itself as the simplest amplifier to analyze since it has infinite input impedance and acts as a voltage amplifier.

Figure 32. Arduino simple test program code to experiment with the local oscillator and bandpass filters. The local oscillator is set for 9MHz and multiplexer select lines

The design guide will be helpful to those unsure of where to start in the design process of an SDR receiver. We included a few issues that we encountered and possible solutions to them so that others can avoid the problems we had.

The details and instructions compiled in this paper are catered towards making the study and design of SDR receivers more accessible to a wide audience. With the information and time barrier lowered, we hope ham radio operators of a wider range of ages and expertise can discover the joys of designing and building a self-tailored software-defined radio with a thin wallet.

i
“US Amateur Radio Population Grows Slightly in 2018.” ARRL: The National Association for Amateur Radio, 14 Feb. 2019, www.arrl.org/news/us-amateur-radio-population-grows-slightly-in-2018. (http://www.arrl.org/news/us-amateur-radio-population-grows-slightly-in-2018)

ii Pepitone, Julianne. “The Uncertain Future of Ham Radio.” IEEE Spectrum: Technology, Engineering, and Science News, 10 July 2020, spectrum.ieee.org/telecom/wireless/the-uncertain-future-of-ham-radio.

iii
“Si5351a CLK0 and CLK1 Signals.” Groups.io, 12 Aug. 2020, https://groups.io/g/ucx/topic/76162126#

iv Kebede, Zenaneh Ashebir. “Low frequency Quadrature detector design, simulation and implementation for use in underground communication.” 2014. Graduate Theses, Dissertations, and Problem Reports. 219. https://researchrepository.wvu.edu/etd/219.

v Soer, Michiel. “Analysis and comparison of switch-based frequency converters.” University of Twente: Faculty of Electrical Engineering, Mathematics & Computer Science, Sept. 2007, https://essay.utwente.nl/58276/1/scriptie_Soer.pdf.

vi Youngberg, Gerald. “A Software Defined Radio for the Masses, Part 4.” QEX, Mar./Apr. 2003, http://www.arrl.org/files/file/Technology/tis/info/pdf/030304qex020.pdf.

vii “More on Ground Loops and Audio Settings - g4zfqradio.” Google Sites, Aug. 2011, sites.google.com/site/g4zfqradio/more-on-ground-loops-and-audio-settings.

viii Kicad is an EE schematic design tool, https://kicad-pcb.org/

ix Notes, Electronics. “RF & Microwave Filters: the Basics.” Electronics Notes, www.electronics-notes.com/articles/radio/rf-filters/understanding-rf-filters-basics-tutorial.php. (http://www.electronics-notes.com/articles/radio/rf-filters/understanding-rf-filters-basics-tutorial.php)

x
“Si5351A Breakout Board.” Si5351A Breakout Board | Etherkit Documentation,
etherkit.github.io/si5351abb_landing_page.

xi Soer, Michiel. “Analysis and Comparison of Switch-Based Frequency Converters.” University of Twente, Faculty of Electrical Engineering, Mathematics & Computer Science, 2007.

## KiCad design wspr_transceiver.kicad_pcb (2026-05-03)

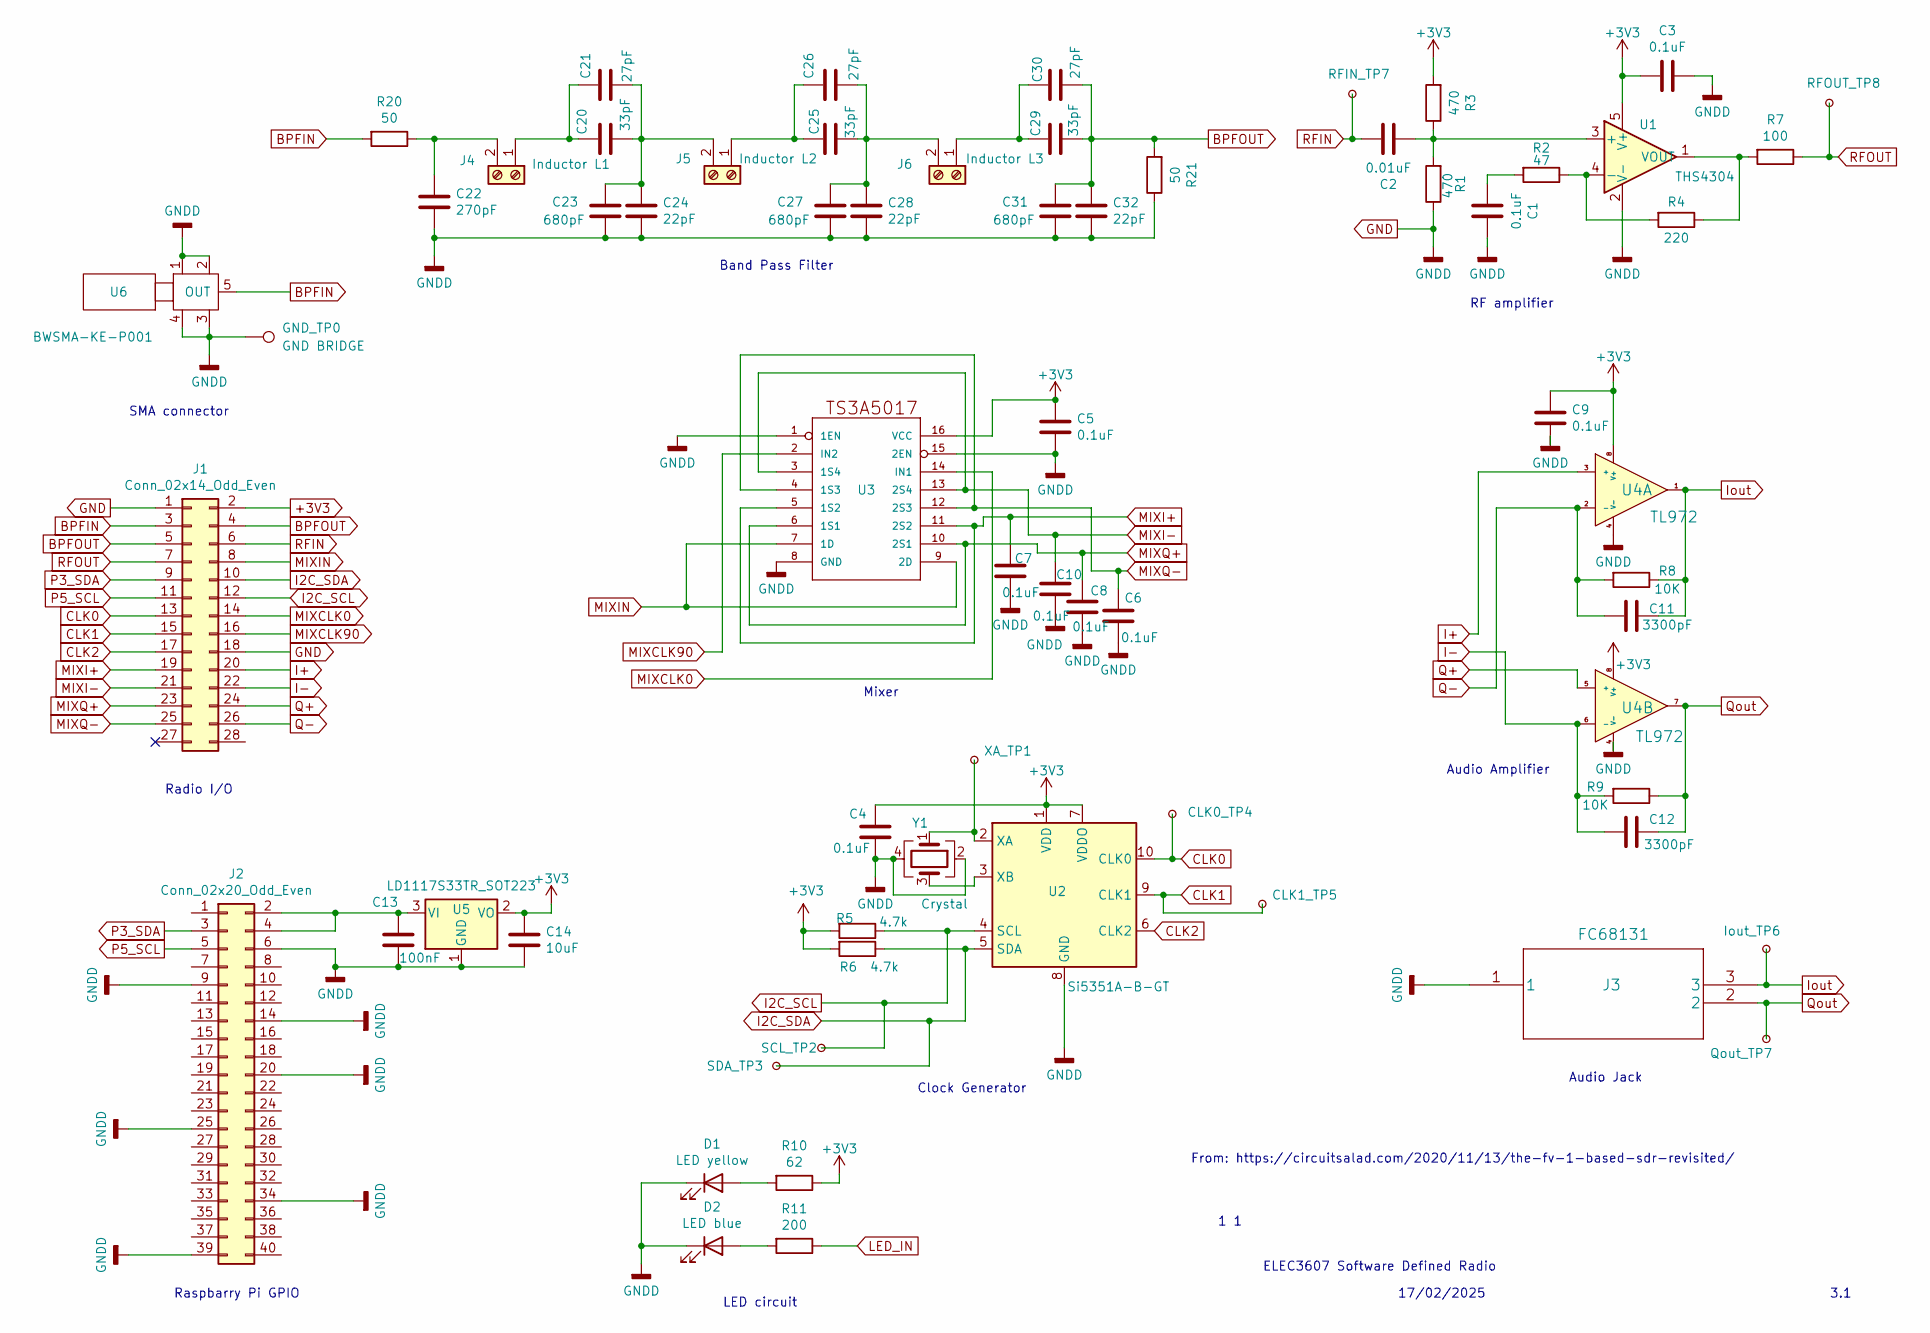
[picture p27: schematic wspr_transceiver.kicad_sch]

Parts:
C1, C3, C4, C5, C6, C7, C8, C9, C10: 0.1uF; C_0805_2012Metric
C2: 0.01uF; C_0805_2012Metric
C11, C12: 3300pF; C_0805_2012Metric
C13: 100nF; C_0805_2012Metric
C14: 10uF; C_0805_2012Metric
C20, C25, C29: 33pF; C_0805_2012Metric
C21, C26, C30: 27pF; C_0805_2012Metric
C22: 270pF; C_0805_2012Metric
C23, C27, C31: 680pF; C_0805_2012Metric
C24, C28, C32: 22pF; C_0805_2012Metric
CLK0_TP4, CLK1_TP5: TestPoint_Small; TestPoint_Keystone_5000-5004_Miniature
D1: LED yellow; D_0603_1608Metric
D2: LED blue; D_0603_1608Metric
GND_TP0: GND BRIDGE; TestPoint_Bridge_Pitch7.62mm_Drill1.3mm
Iout_TP6: TestPoint_Small; TestPoint_Keystone_5000-5004_Miniature
J1: Conn_02x14_Odd_Even; PinHeader_2x14_P2.54mm_Vertical
J2: Conn_02x20_Odd_Even; PinHeader_2x20_P2.54mm_Vertical
J3: FC68131
J4: Inductor L1; TerminalBlock_Phoenix_MPT-0,5-2-2.54_1x02_P2.54mm_Horizontal
J5: Inductor L2; TerminalBlock_Phoenix_MPT-0,5-2-2.54_1x02_P2.54mm_Horizontal
J6: Inductor L3; TerminalBlock_Phoenix_MPT-0,5-2-2.54_1x02_P2.54mm_Horizontal
Qout_TP7: TestPoint_Small; TestPoint_Keystone_5000-5004_Miniature
R1, R3: 470; R_0805_2012Metric
R2: 47; R_0805_2012Metric
R4: 220; R_0805_2012Metric
R5, R6: 4.7k; R_0805_2012Metric
R7: 100; R_0805_2012Metric
R8, R9: 10K; R_0805_2012Metric
R10: 62; R_0805_2012Metric
R11: 200; R_0805_2012Metric
R20, R21: 50; R_0805_2012Metric
RFIN_TP7: TestPoint_Small; TestPoint_Keystone_5000-5004_Miniature
RFOUT_TP8: TestPoint_Small; TestPoint_Keystone_5000-5004_Miniature
SCL_TP2: TestPoint_Small; TestPoint_Keystone_5000-5004_Miniature
SDA_TP3: TestPoint_Small; TestPoint_Keystone_5000-5004_Miniature
U1: THS4304; SOT-23-5
U2: Si5351A-B-GT; MSOP-10_3x3mm_P0.5mm
U3: TS3A5017; SOIC-16_3.9x9.9mm_P1.27mm
U4: TL972; SOIC-8-1EP_3.9x4.9mm_P1.27mm_EP2.29x3mm
U5: LD1117S33TR_SOT223; SOT-223-3_TabPin2
U6: BWSMA-KE-P001
XA_TP1: TestPoint_Small; TestPoint_Keystone_5000-5004_Miniature
Y1: Crystal; Crystal_SMD_TXC_7M-4Pin_3.2x2.5mm

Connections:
+3V3: C3.2, C4.1, C5.1, C9.1, C14.1, J1.2, R3.2, R5.2, R6.2, R10.1, U1.5 (V+), U2.1 (VDD), U2.7 (VDDO), U3.16 (VCC), U4.8 (V+), U5.2 (VO)
BPFIN: J1.3, R20.2, U6.5 (OUT)
BPFOUT: C29.2, C30.2, C31.1, C32.1, J1.4, J1.5, R21.2
CLK0: CLK0_TP4.1, J1.13, U2.10 (CLK0)
CLK1: CLK1_TP5.1, J1.15, U2.9 (CLK1)
CLK2: J1.17, U2.6 (CLK2)
GND: C1.1, C3.1, C4.2, C5.2, C6.2, C7.2, C8.2, C9.2, C10.2, C13.2, C14.2, C22.2, C23.2, C24.2, C27.2, C28.2, C31.2, C32.2, D1.1 (K), D2.1 (K), GND_TP0.1, J1.1, J1.18, J2.6, J2.9, J2.14, J2.20, J2.25, J2.34, J2.39, J3.1, R1.1, R21.1, U1.2 (V-), U2.8 (GND), U3.1 (1EN), U3.8 (GND), U3.15 (2EN), U4.4 (V-), U5.1 (GND), U6.1, U6.2, U6.3, U6.4, Y1.2, Y1.4
I2C_SCL: J1.12, R5.1, SCL_TP2.1, U2.4 (SCL)
I2C_SDA: J1.10, R6.1, SDA_TP3.1, U2.5 (SDA)
I+: J1.20, U4.3 (+)
I-: C12.2, J1.22, R9.2, U4.6 (-)
Iout: C11.1, Iout_TP6.1, J3.3, R8.1, U4.1
LED_IN: R11.1
MIXCLK0: J1.14, U3.14 (IN1)
MIXCLK90: J1.16, U3.2 (IN2)
MIXI+: C7.1, J1.19, U3.5 (1S2), U3.11 (2S2)
MIXI-: C10.1, J1.21, U3.3 (1S4), U3.13 (2S4)
MIXIN: J1.8, U3.7 (1D), U3.9 (2D)
MIXQ+: C8.1, J1.23, U3.6 (1S1), U3.10 (2S1)
MIXQ-: C6.1, J1.25, U3.4 (1S3), U3.12 (2S3)
unnamed: C1.2, R2.2
unnamed: D1.2 (A), R10.2
unnamed: D2.2 (A), R11.2
unnamed: C13.1, J2.2, J2.4, U5.3 (VI)
unnamed: C20.1, C21.1, J4.1
unnamed: C22.1, J4.2, R20.1
unnamed: C25.1, C26.1, J5.1
unnamed: C20.2, C21.2, C23.1, C24.1, J5.2
unnamed: C29.1, C30.1, J6.1
unnamed: C25.2, C26.2, C27.1, C28.1, J6.2
unnamed: C2.2, R1.2, R3.1, U1.3 (+)
unnamed: R2.1, R4.2, U1.4 (-)
unnamed: R4.1, R7.2, U1.1 (VOUT)
unnamed: U2.2 (XA), XA_TP1.1, Y1.1
unnamed: U2.3 (XB), Y1.3
P3_SDA: J1.9, J2.3
P5_SCL: J1.11, J2.5
Q+: J1.24, U4.5 (+)
Q-: C11.2, J1.26, R8.2, U4.2 (-)
Qout: C12.1, J3.2, Qout_TP7.1, R9.1, U4.7
RFIN: C2.1, J1.6, RFIN_TP7.1
RFOUT: J1.7, R7.1, RFOUT_TP8.1

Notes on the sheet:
Audio Amplifier
LED circuit
SMA connector
Raspbarry Pi GPIO
Audio Jack
17/02/2025
Radio I/O
Clock Generator
ELEC3607 Software Defined Radio
3.1
From: https://circuitsalad.com/2020/11/13/the-fv-1-based-sdr-revisited/
Band Pass Filter
Mixer
1 1
RF amplifier

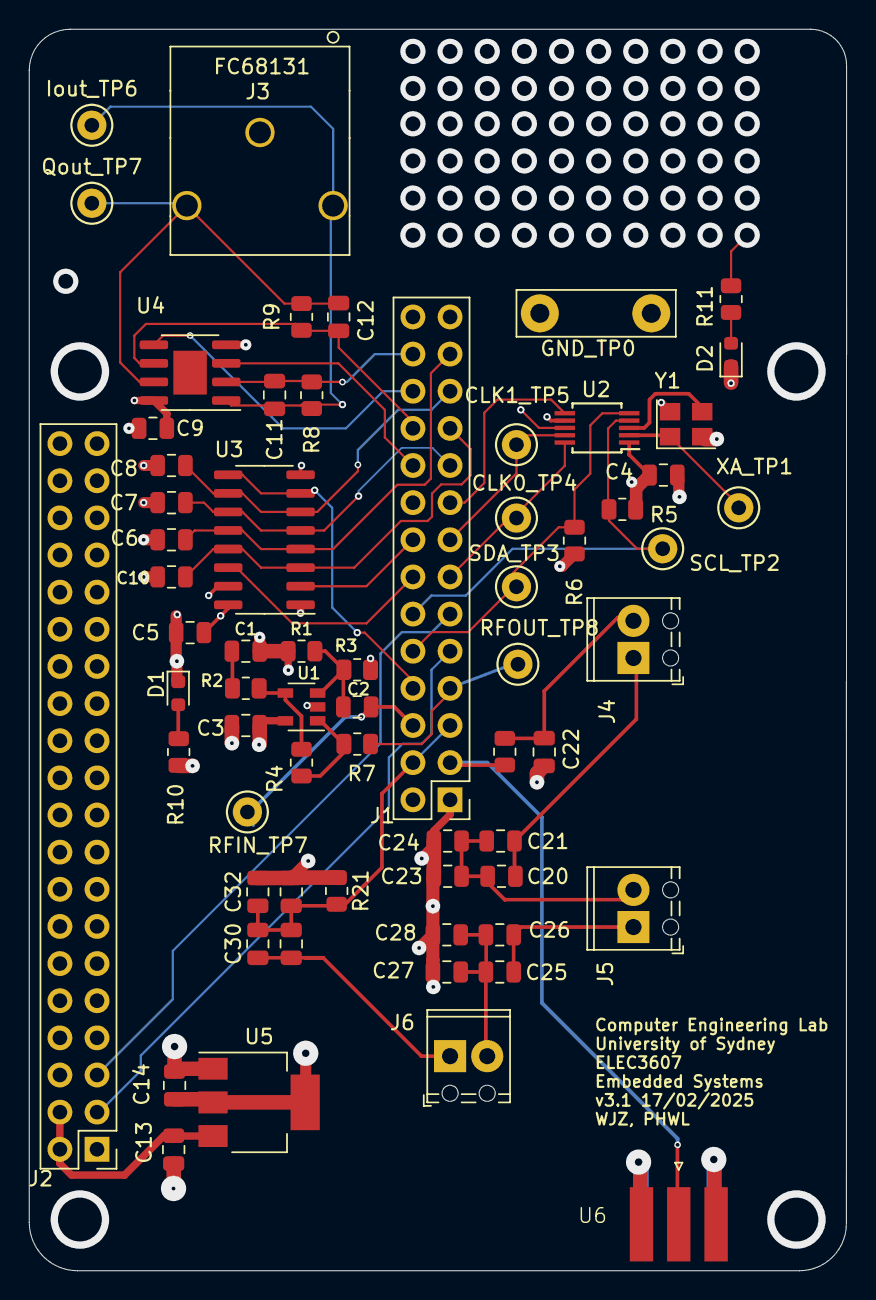
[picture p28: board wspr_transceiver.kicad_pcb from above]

Board: 4 copper layers, 55.9 x 84.9 mm, 65 parts (0 on the bottom side), 41 nets.

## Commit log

2026-05-03 Initial WSPR transceiver project files
    [bbb-B_Cu.gbl, bbb-B_Mask.gbs, bbb-B_Paste.gbp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]
2026-05-03 Create transceiver KiCad project copy
    [wspr_transceiver.kicad_pcb, wspr_transceiver.kicad_sch]
2026-05-03 Document hardware architecture from schematic image

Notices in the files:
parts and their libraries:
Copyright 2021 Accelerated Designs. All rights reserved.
